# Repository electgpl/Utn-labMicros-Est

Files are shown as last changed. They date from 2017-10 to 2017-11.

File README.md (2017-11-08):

Estación Meteorológica Inalámbrica
=============================

### Introducción
 
Se presentará una estación meteorológica inalámbrica hogareña, la misma consta de dos dispositivos individuales, una estación meteorológica interna que provee de valores dentro del recinto donde se encuentra, y una estación meteorológica externa que provee los valores exteriores, entre ambos dispositivos se realiza la telemetría exterior y se muestra en un display alfanumérico en la estación interior, con la finalidad de observar a primera vista los datos meteorológicos internos y externos.
Esta estación funciona de forma inalámbrica con enlaces de radiofrecuencia y funciona con pilas primarias en el caso exterior y batería recargable en el caso interior.

El proyecto surge de la idea de practicar la programación en lenguaje C, los protocolos de comunicación serie y el transporte de los datos vía enlaces inalambricos, en este proyecto se abordará la estructura necesaria para realizar una trama de datos básica, su payload y verificación.
También se realizará la puesta en marcha del sistema mediante electrónica de bajo costo y bajo consumo para afrontar el problema energético que conlleva la utilización de pilas y baterías de forma competitiva con productos comerciales de la actualidad.

----------
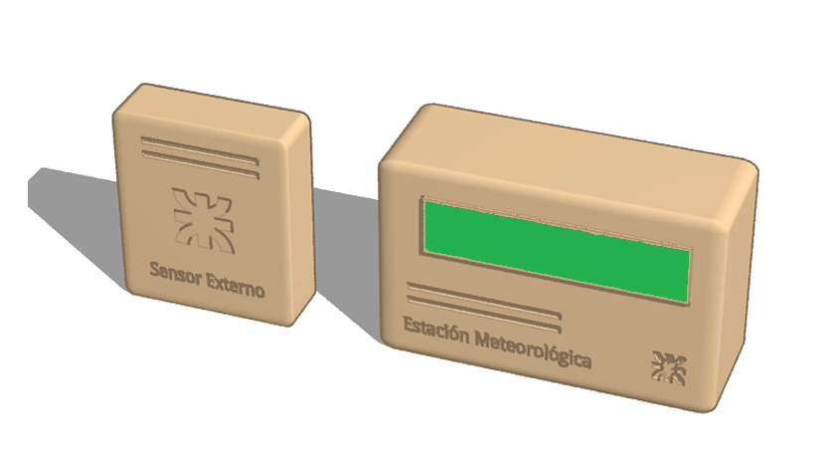
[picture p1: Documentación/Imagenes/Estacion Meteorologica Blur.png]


----------

### Objetivos
 
- Estación meteorológica con medición interna y externa.
- La estación consiste en un sensor externo y uno interno. 
- El sensor externo posee la capacidad de medir Temperatura, Humedad y Luminosidad. 
- El sensor interno mide Temperatura y Humedad. 
- La telemetría se realiza mediante un enlace inalámbrico simplex UHF, el sensor externo funciona mediante celdas primarias alcalinas y posee electrónica de bajo consumo proporcionando una autonomía de 1 año.
- El sensor interno posee un display de LCD de 2 lineas y 16 caracteres que mostrará la Temperatura y Humedad del sensor interno, la Temperatura, Humedad y Luminosidad del sensor externo.
- El sensor interno cuenta con una batería secundaria de iones de litio recargable mediante un conector micro usb.

> **Nota:**
> - El microcontrolador utilizado se basa en core 8051 (para el cual el firmware se encuentra compilado con Keil sobre un microcontrolador de Silabs C8051F832).
> - Se ha realizado también para Microchip sobre diversas plataformas
> - La simulación se realiza para Microchip sobre Proteus.
> - Los diagramas, PCB y Gerber, son realizados con Eagle.

----------

### Diseño conceptual
 
Para realizar nuestra estación, utilizaremos microcontroladores modernos de bajo consumo y bajo costo, que permite trabajar con una buena autonomía utilizando pilas primarias para aumentar al máximo el rendimiento del sistema.
La estación meteorológica utilizara la función especial del microcontrolador para entrar en modo bajo consumo y así extender la batería.
Una vez en bajo consumo se despertara de forma automática mediante el WDT del microcontrolador cada 10 segundos, se tomará una muestra de temperatura, humedad y luminosidad, se enviará mediante el enlace de RF a la estación interna y luego se volverá a dormir entrando en bajo consumo.
El enlace se ha simplificado al máximo para reducir el costo, se utiliza modulación ASK en UHF mediante oscilador a cristal SAW de 433.92MHz y se enviaran los datos mediante UART invertida a 600bps.
En la estación interior, se utilizara la interrupción de dato presente en UART para atender la telemetría exterior, realizar el parse de la trama y dejarla disponible para la utilización.
Se tomará humedad y temperatura interior, y junto con la telemetría exterior se mostrará todo en un dsiplay LCD de 2x16 caracteres alfanuméricos.
La estación interna cuenta con baterías recargables y su controlador de carga para ser conectado directamente con un cable estándar micro usb.

----------
## Implementación
### Especificaciones de Hardware:
#### Dispositivo Interno:
- Sensor de Temperatura y Humedad, DHT11 (comunicación onWire propietaria).
- Receptor modular RWS simplex UHF operando en la banda de 70cm en 433.92MHz, modulación ASK OOK utilizando protocolo RS232, Antena del tipo microstrip IFA 50 Ohms.
- Display LCD 2x16 con controlador HD44780, para mostrar Temp, Hum, (Interna y Externa), Luminosidad (Externa).
- Cargador de Batería tipo Secundaria Li-Ion con micro USB basado en controlador TP4056, Celda 18650, 4800mAh (típico) .
- Microcontrolador de 8bit Silabs C8051F832.
- Circuito impreso hasta 2 Layer con PTH y tecnologia SMD. 
- Aceptación IPC-356, IPC-600, UL-94.

#### Dispositivo Externo:
- Sensor de Temperatura y Humedad, DHT11 (comunicación onWire propietaria).
- Sensor de Luminosidad basado en LDR con acondicionamiento por firmware.
- Transmisor modular TWS simplex UHF operando en la banda de 70cm en 433.92MHz, modulación ASK OOK utilizando protocolo RS232, Antena del tipo microstrip IFA 50 Ohms.
- Batería del tipo primaria alcalina ZnMnO2 tamaño AA, 2500mAh (típico).
- Microcontrolador de 8bit Silabs C8051F832.
- Circuito impreso hasta 2 Layer con PTH y tecnologia SMD. 
- Aceptación IPC-356, IPC-600, UL-94.

### Especificaciones de Firmware:
El firmware debe contar con estándares de programación, encabezado del programa, descripción, autores, versionado, fechas y referencias.
Las funciones deben contar con los valores de ingreso y egreso a la misma como así el tipo de datos y la descripción de la función.
El programa se realizará en lenguaje C.

- Desarrollo de Bibliotecas necesarias (Estandarizado)
- Pruebas Unitarias de cada Biblioteca con el hardware asociado
- Desarrollo de programa principal
- Manejo de errores
- Creación de diagramas de flujo o estado
- Pruebas Integrados del firmware con todas las Bibliotecas y devices

-------
- Biblioteca para sensor DHT11
>- Manejo de Bus OneWire 5 bytes (4 bytes de datos 1 byte de checksum)
>- Formateo de datos de salida Temperatura: entero sin signo de 8bit
>- Formateo de datos de salida Humedad: entero sin signo de 8bit

- Biblioteca de control del LCD
>- Mapeo de los 2 renglones y 16 caracteres.
>- Control de memoria mediante bus de 4bit y control.
>- Entrada mediante string con control xy de caracteres.

- Biblioteca bitbanging para protocolo manchester en los enlaces UHF
>- BitBanging de del protocolo.
>- Realización de Checksum
>- Salida de datos en formato hexadecimal.
>- Entrada de datos en formato hexadecimal.

- Biblioteca del sensor de luminosidad
>- Utilización del conversor analogico digital provisto por el microcontrolador.
>- Configuración de baja velocidad a resolución de 8bit.
>- Salida datos en formato entero.

- Manejo de Baja Energía
>- Apagado de dispositivos periféricos en desuso mediante transistores NMOS.
>- Reloj WDT para función WakeUp del MCU cada 2.3s
>- Si los datos a medir (sensores) no cambian respecto a la medición anterior, no se enviaran datos repetidos mejorando el consumo.

--------

### Especificaciones Técnicas:

Rango de temperatura 0-50°c (precisión ±2°c) 
Rango de humedad 20-90%RH (precisión ±5％) 
Rango de luminosidad 0-100% (precisión ±20％)    
Rango de trabajo hasta 20m Frecuencia de trabajo 433MHz 
Batería de sensor 2xAA Alcalina 
Vida útil de 2 años 
Batería de cuerpo 1x18650
Vida útil Recargable via USB 
Medidas cuerpo 113x67x27.5mm 
Medidas Sensor 91x70x32.5mm 
Gabinete exterior IPX3 
Este equipo no dispone de protección ATEX, por lo que no debe ser usado en atmósferas potencialmente explosivas (polvo, gases inflamables).

--------

### Conclusiones
 
Se ha logrado implementar una estación meteorológica hogareña de bajo consumo y bajo costo que presenta una propuesta comercial respecto a las competidoras de mismas prestaciones.

Se implementó el código necesario para realizar el proyecto sobre core 8051 bajo una plataforma moderna que opera en 16MHz y 16MIPS.
Se realizó todo el tratamiento de la trama, preámbulo, payload, checksum y parseo de datos para realizar el enlace de telemetría entre los dos dispositivos.
Se analizó la velocidad de transferencia de datos sobre UART para lograr la mejor comunicación y alcance sobre módulos de RF de bajo costo.
Se comprobó el diseño de la antena con la ayuda de instrumental adecuado “VNA” para su correcta adaptación.

--------

### Bibliografía
 
- [1] “Manual 8051 Keil”, 
http://www.keil.com/support/man/docs/is51/
- [2] “Manual Eagle”, 
http://hades.mech.northwestern.edu/images/b/b4/Eagle_Manual.pdf
- [3] “Norma ATEX”, 
http://www.insht.es/InshtWeb/Contenidos/Normativa/GuiasTecnicas/Ficheros/ATM%C3%93SFERAS%20EXPLOSIVAS.pdf
- [4] “Norma IPX3”, 
http://hades.mech.northwestern.edu/images/b/b4/Eagle_Manual.pdfhttp://www.f2i2.net/documentos/lsi/rbt/guias/guia_bt_anexo_1_sep03R1.pdf
- [5] “Norma IPC610”, 
http://www.ipc.org/TOC/IPC-A-610E-Spanish.pdf
- [6] “Datasheet DHT11”, 
https://akizukidenshi.com/download/ds/aosong/DHT11.pdf
- [7] “Datasheet Modulos Transmisor y Receptor RF UHF”, https://4.imimg.com/data4/AJ/NM/MY-1833510/rf-transmitter-receiver-pair-433-mhz-ask.pdf
- [8] “Datasheet LDR”, 
http://kennarar.vma.is/thor/v2011/vgr402/ldr.pdf
- [9] “Datasheet C8051F832 Silabs”, https://www.silabs.com/documents/public/data-sheets/C8051F80x-83x.pdf
- [10] “Datasheet TP4056”, https://dlnmh9ip6v2uc.cloudfront.net/datasheets/Prototyping/TP4056.pdf

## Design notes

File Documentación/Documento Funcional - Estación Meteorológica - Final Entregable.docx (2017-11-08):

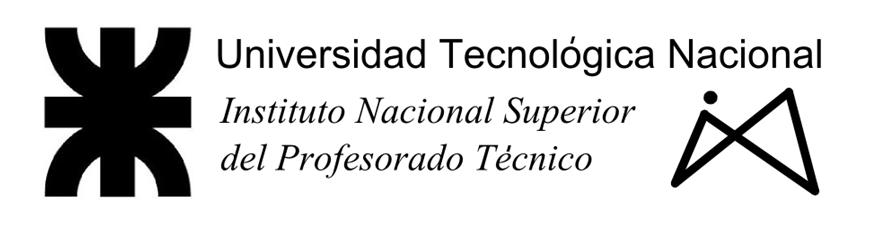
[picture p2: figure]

Robótica

Materia: Laboratorio de Microprocesadores

Curso: 3-631

Año: 2017

Trabajo Práctico Nro. 1

Argumento: Proyecto - Estación Meteorológica Inalámbrica.

Integrantes del Equipo: Caccavallo, Sebastian

Gerbec, Rodrigo

Leuenberger, Leonardo

Responsable del Informe: Caccavallo Sebastian

Profesor: Steiner, Daniel.

Fecha de realización del T.P. | / /
1ra. Fecha de presentación | / /
2da. Fecha de presentación | / /
Calificación
Fecha de Aprobación | / /
FIRMA: ………………………. | ACLARACIÓN: ……………….………………...

Introducción

Se presentará una estación meteorológica inalámbrica hogareña, la misma consta de dos dispositivos individuales, una estación meteorológica interna que provee de valores dentro del recinto donde se encuentra, y una estación meteorológica externa que provee los valores exteriores, entre ambos dispositivos se realiza la telemetría exterior y se muestra en un display alfanumérico en la estación interior, con la finalidad de observar a primera vista los datos meteorológicos internos y externos.

Esta estación funciona de forma inalámbrica con enlaces de radiofrecuencia y funciona con pilas primarias en el caso exterior y batería recargable en el caso interior.

El proyecto surge de la idea de practicar la programación en lenguaje C, los protocolos de comunicación serie y el transporte de los datos vía enlaces inalambricos, en este proyecto se abordará la estructura necesaria para realizar una trama de datos básica, su payload y verificación.

También se realizará la puesta en marcha del sistema mediante electrónica de bajo costo y bajo consumo para afrontar el problema energético que conlleva la utilización de pilas y baterías de forma competitiva con productos comerciales de la actualidad.

Objetivos

- Estación meteorológica con medición interna y externa.
- La estación consiste en un sensor externo y uno interno.
- El sensor externo posee la capacidad de medir Temperatura, Humedad y Luminosidad.
- El sensor interno mide Temperatura y Humedad.
- La telemetría se realiza mediante un enlace inalámbrico simplex UHF, el sensor externo funciona mediante celdas primarias alcalinas y posee electrónica de bajo consumo proporcionando una autonomía de 1 año.
- El sensor interno posee un display de LCD de 2 lineas y 16 caracteres que mostrará la Temperatura y Humedad del sensor interno, la Temperatura, Humedad y Luminosidad del sensor externo.
- El sensor interno cuenta con una batería secundaria de iones de litio recargable mediante un conector micro usb.
- Look&Feel del LCD (VER FIGURA EN EL APARTADO)

Diseño conceptual

Para realizar nuestra estación, utilizaremos microcontroladores modernos de bajo consumo y bajo costo, que permite trabajar con una buena autonomía utilizando pilas primarias para aumentar al máximo el rendimiento del sistema.

La estación meteorológica utilizara la función especial del microcontrolador para entrar en modo bajo consumo y así extender la batería.

Una vez en bajo consumo se despertara de forma automática mediante el WDT del microcontrolador cada 10 segundos, se tomará una muestra de temperatura, humedad y luminosidad, se enviará mediante el enlace de RF a la estación interna y luego se volverá a dormir entrando en bajo consumo.

El enlace se ha simplificado al máximo para reducir el costo, se utiliza modulación ASK en UHF mediante oscilador a cristal SAW de 433.92MHz y se enviaran los datos mediante UART invertida a 600bps.

En la estación interior, se utilizara la interrupción de dato presente en UART para atender la telemetría exterior, realizar el parse de la trama y dejarla disponible para la utilización.

Se tomará humedad y temperatura interior, y junto con la telemetría exterior se mostrará todo en un dsiplay LCD de 2x16 caracteres alfanuméricos.

La estación interna cuenta con baterías recargables y su controlador de carga para ser conectado directamente con un cable estándar micro usb.

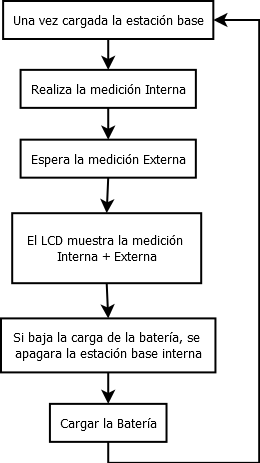
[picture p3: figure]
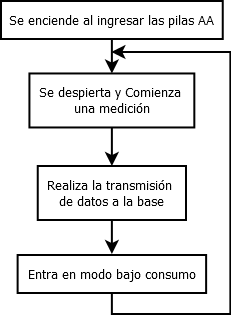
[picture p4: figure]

Diseño de alto nivel

Diagrama de bloques de Hardware Interior:

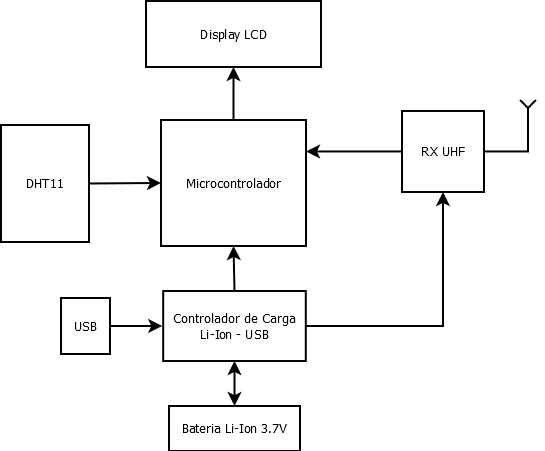
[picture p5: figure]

Diagrama de bloques de Hardware Exterior:

Diagrama de bloques de Firmware Interior:

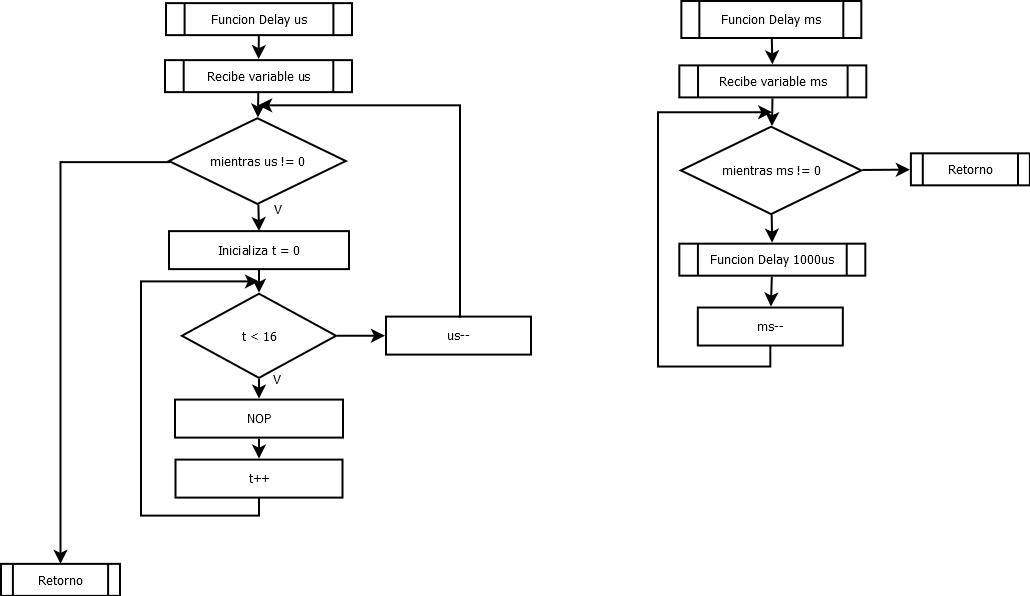
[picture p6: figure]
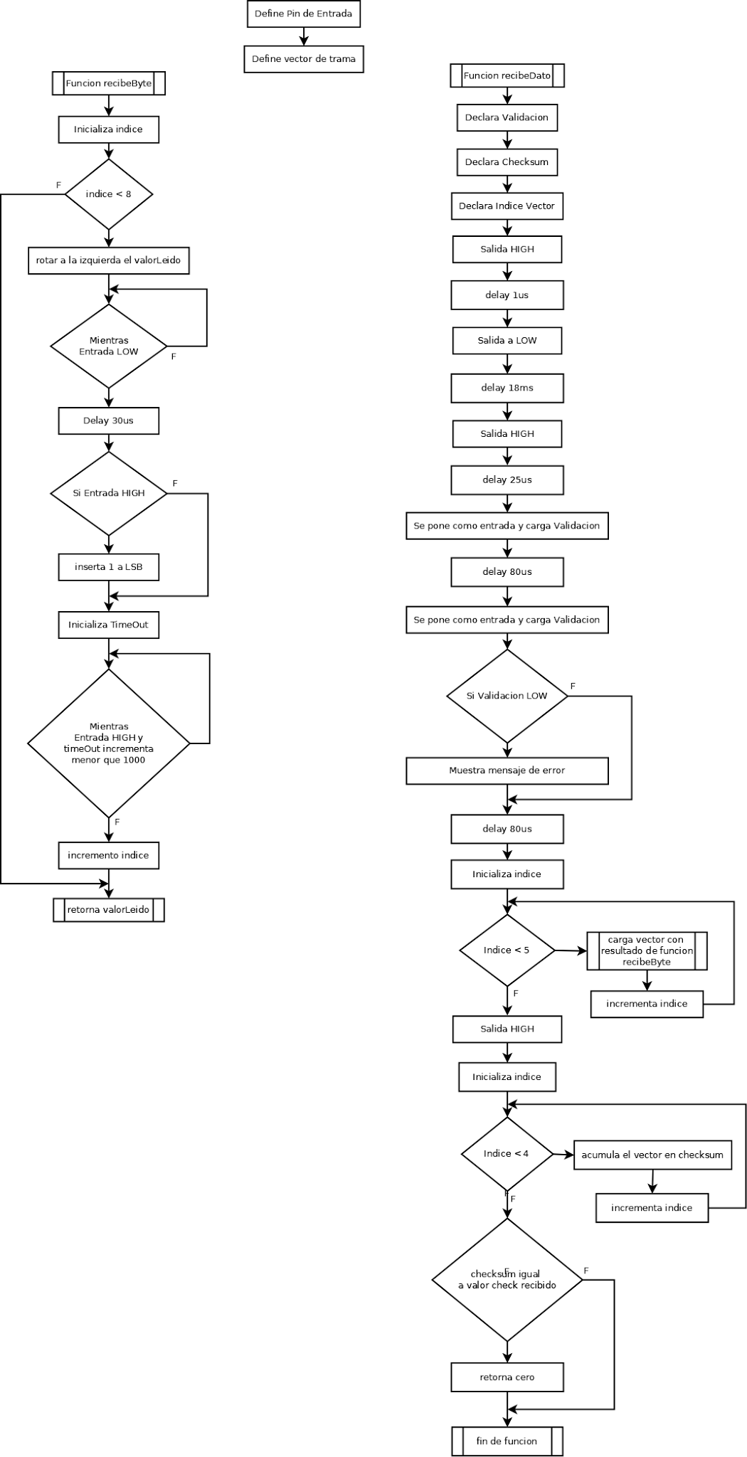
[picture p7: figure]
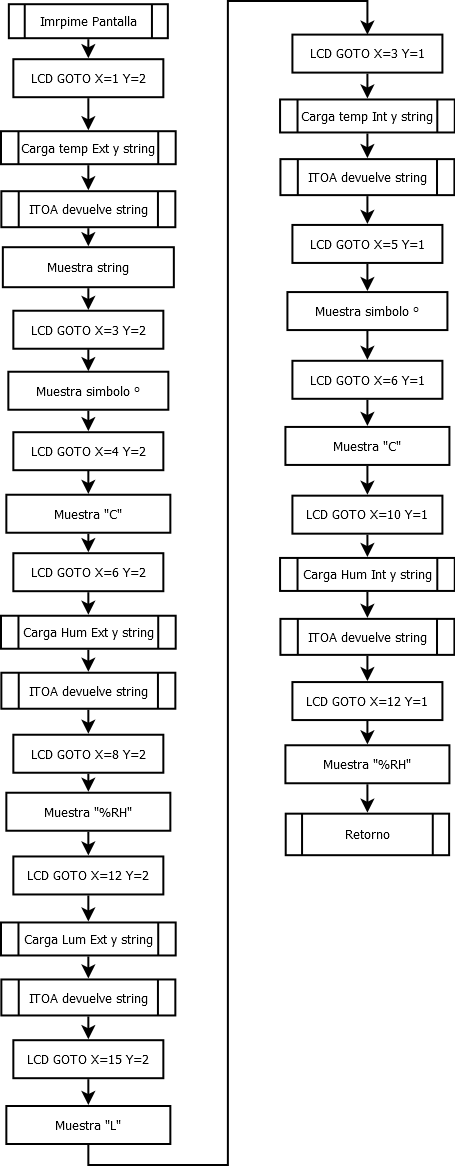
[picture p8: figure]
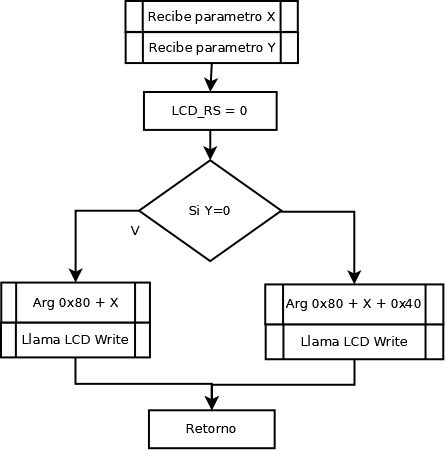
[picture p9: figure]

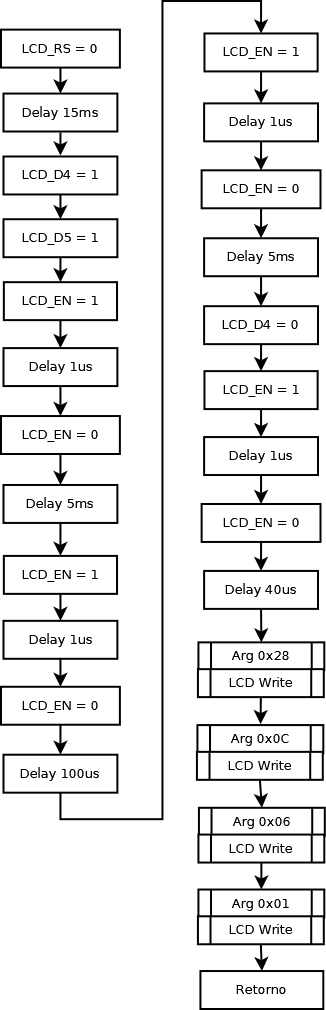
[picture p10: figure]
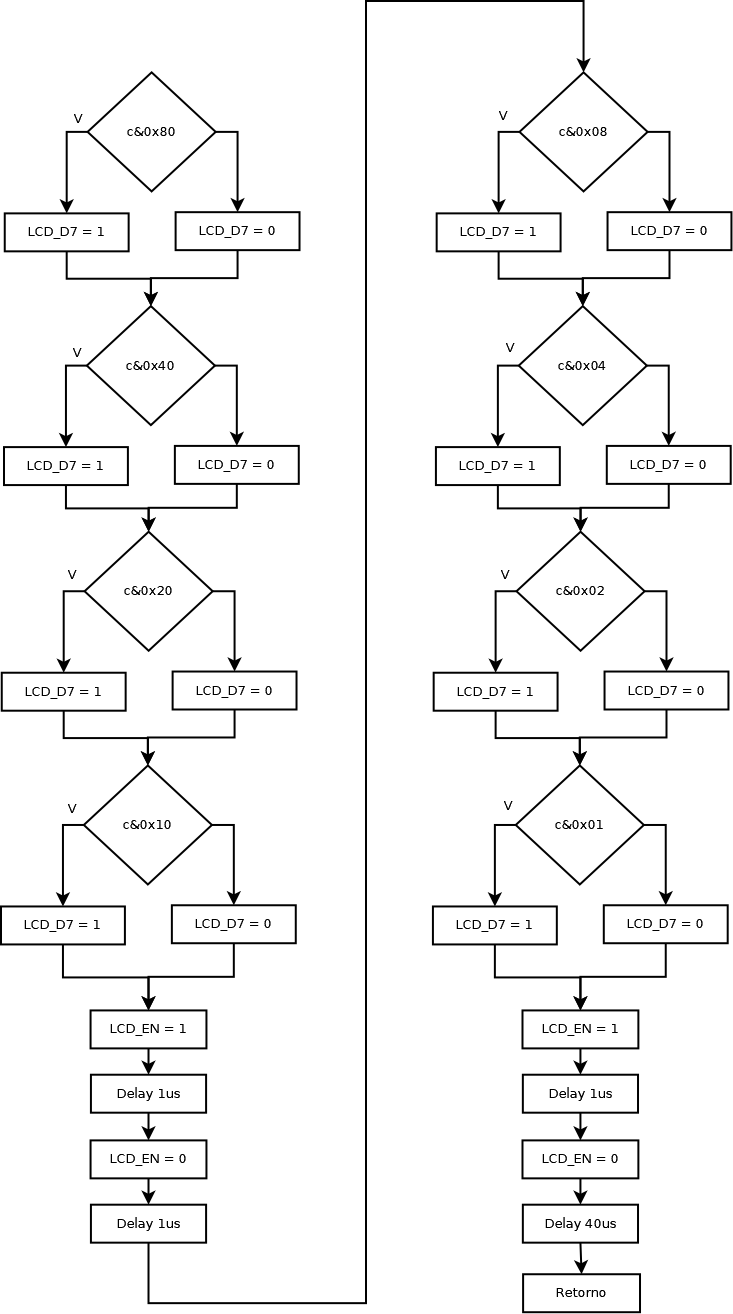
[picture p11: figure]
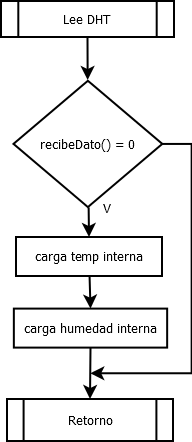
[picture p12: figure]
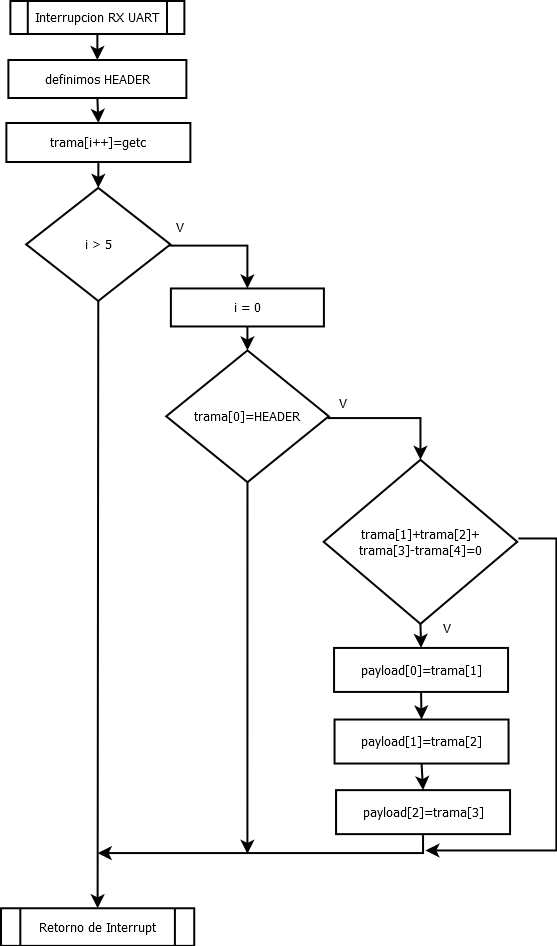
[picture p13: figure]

Diagrama de bloques de Firmware Exterior:

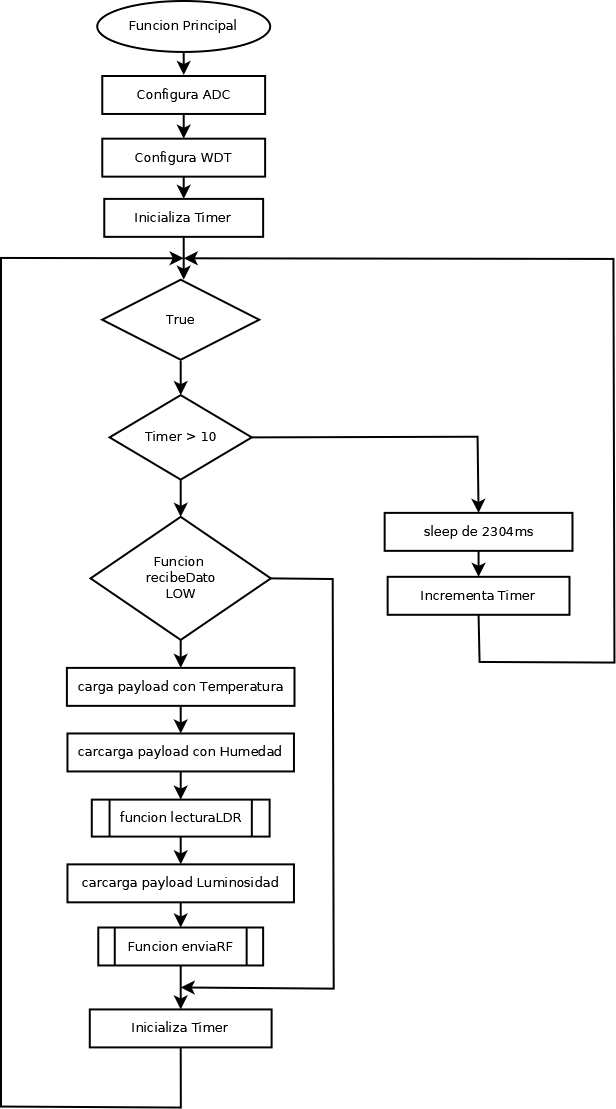
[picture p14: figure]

Implementación

### Especificaciones de Hardware:

### Dispositivo Interno:

- Sensor de Temperatura y Humedad, DHT11 (comunicación onWire propietaria).
- Receptor modular RWS simplex UHF operando en la banda de 70cm en 433.92MHz, modulación ASK OOK utilizando protocolo RS232, Antena del tipo microstrip IFA 50 Ohms.
- Display LCD 2x16 con controlador HD44780, para mostrar Temp, Hum, (Interna y Externa), Luminosidad (Externa).
- Cargador de Batería tipo Secundaria Li-Ion con micro USB basado en controlador TP4056, Celda 18650, 4800mAh (típico) .
- Microcontrolador de 8bit Silabs C8051F832.
- Circuito impreso hasta 2 Layer con PTH y tecnologia SMD.
- Aceptación IPC-356, IPC-600, UL-94.

### Dispositivo Externo:

- Sensor de Temperatura y Humedad, DHT11 (comunicación onWire propietaria).
- Sensor de Luminosidad basado en LDR con acondicionamiento por firmware.
- Transmisor modular TWS simplex UHF operando en la banda de 70cm en 433.92MHz, modulación ASK OOK utilizando protocolo RS232, Antena del tipo microstrip IFA 50 Ohms.
- Batería del tipo primaria alcalina ZnMnO2 tamaño AA, 2500mAh (típico).
- Microcontrolador de 8bit Silabs C8051F832.
- Circuito impreso hasta 2 Layer con PTH y tecnologia SMD.
- Aceptación IPC-356, IPC-600, UL-94.

### Especificaciones de Firmware:

El firmware debe contar con estándares de programación, encabezado del programa, descripción, autores, versionado, fechas y referencias.

Las funciones deben contar con los valores de ingreso y egreso a la misma como así el tipo de datos y la descripción de la función.

El programa se realizará en lenguaje C.

- Desarrollo de Bibliotecas necesarias (Estandarizado)
- Pruebas Unitarias de cada Biblioteca con el hardware asociado
- Desarrollo de programa principal
- Manejo de errores
- Creación de diagramas de flujo o estado
- Pruebas Integrados del firmware con todas las Bibliotecas y devices
- Biblioteca para sensor DHT11
  - Manejo de Bus OneWire 5 bytes (4 bytes de datos 1 byte de checksum)
  - Formateo de datos de salida Temperatura: entero sin signo de 8bit
  - Formateo de datos de salida Humedad: entero sin signo de 8bit
- Biblioteca de control del LCD
  - Mapeo de los 2 renglones y 16 caracteres.
  - Control de memoria mediante bus de 4bit y control.
  - Entrada mediante string con control xy de caracteres.
- Biblioteca bitbanging para protocolo manchester en los enlaces UHF
  - BitBanging de del protocolo.
  - Realización de Checksum
  - Salida de datos en formato hexadecimal.
  - Entrada de datos en formato hexadecimal.
- Biblioteca del sensor de luminosidad
  - Utilización del conversor analogico digital provisto por el microcontrolador.
  - Configuración de baja velocidad a resolución de 8bit.
  - Salida datos en formato entero.
- Manejo de Baja Energía
  - Apagado de dispositivos periféricos en desuso mediante transistores NMOS.
  - Reloj WDT para función WakeUp del MCU cada 2.3s
  - Si los datos a medir (sensores) no cambian respecto a la medición anterior, no se enviaran datos repetidos mejorando el consumo.

Especificaciones Técnicas:

Rango de temperatura 0-50°c (precisión ±2°c)
Rango de humedad 20-90%RH (precisión ±5％)

Rango de luminosidad 0-100% (precisión ±20％)

Rango de trabajo hasta 20m
Frecuencia de trabajo 433MHz

Batería de sensor 2xAA Alcalina - Vida útil de 2 años

Batería de cuerpo 1x18650 - Vida útil Recargable via USB

Medidas cuerpo 113x67x27.5mm
Medidas Sensor 91x70x32.5mm

Gabinete exterior IPX3

Este equipo no dispone de protección ATEX, por lo que no debe ser usado en atmósferas potencialmente explosivas (polvo, gases inflamables).

Look & Feel de pantalla:

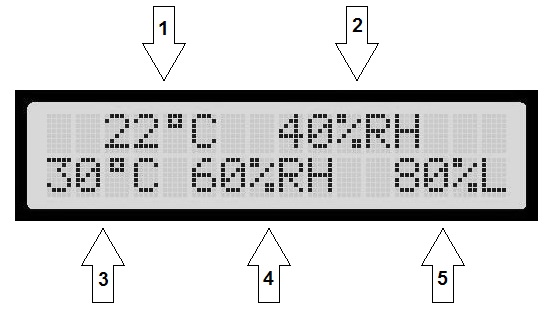
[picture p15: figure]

| 1) Temperatura Interior 2) Humedad Interior 3) Temperatura Exterior 4) Humedad Exterior 5) Cantidad de Luz Exterior

Trama implementada para el enlace:

Diagrama Electronico Interior:

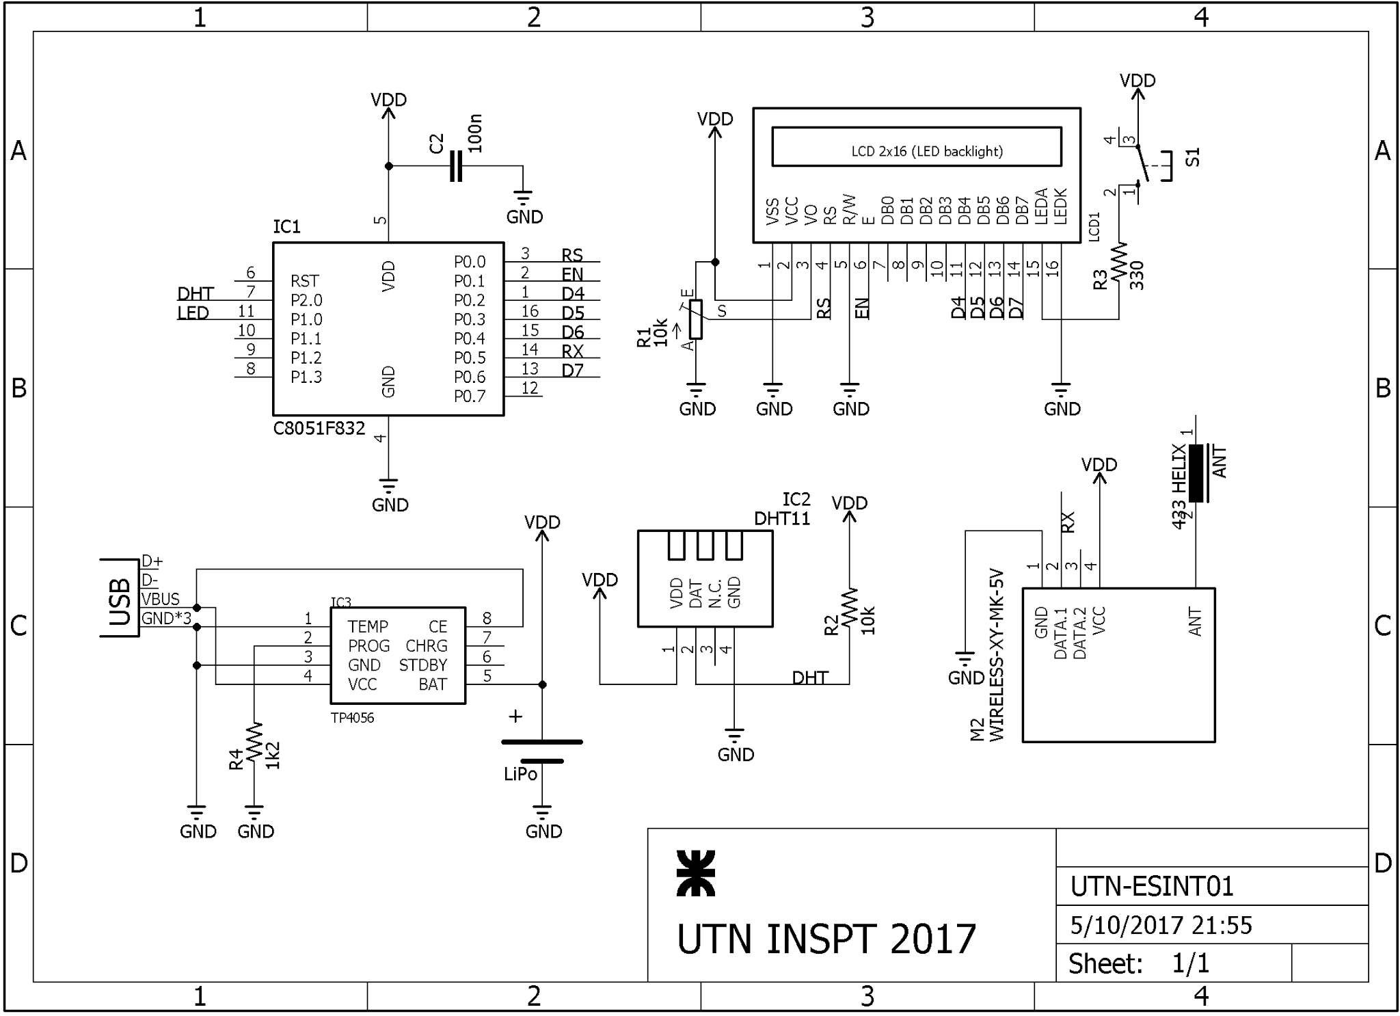
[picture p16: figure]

Diagrama Electronico Exterior:

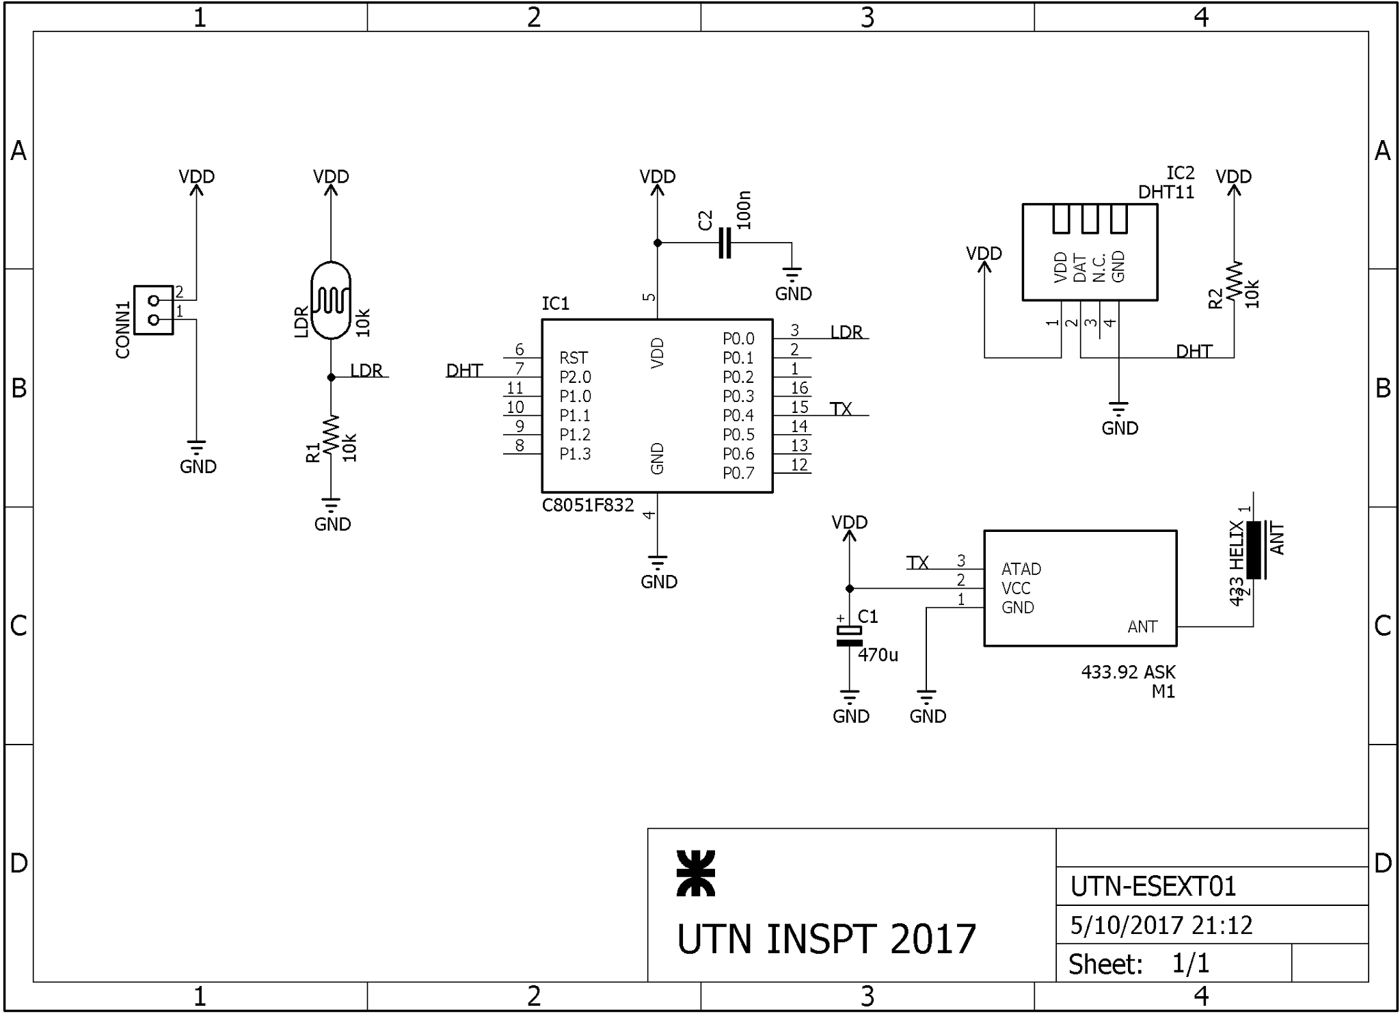
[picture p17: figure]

Circuito Impreso Interior:

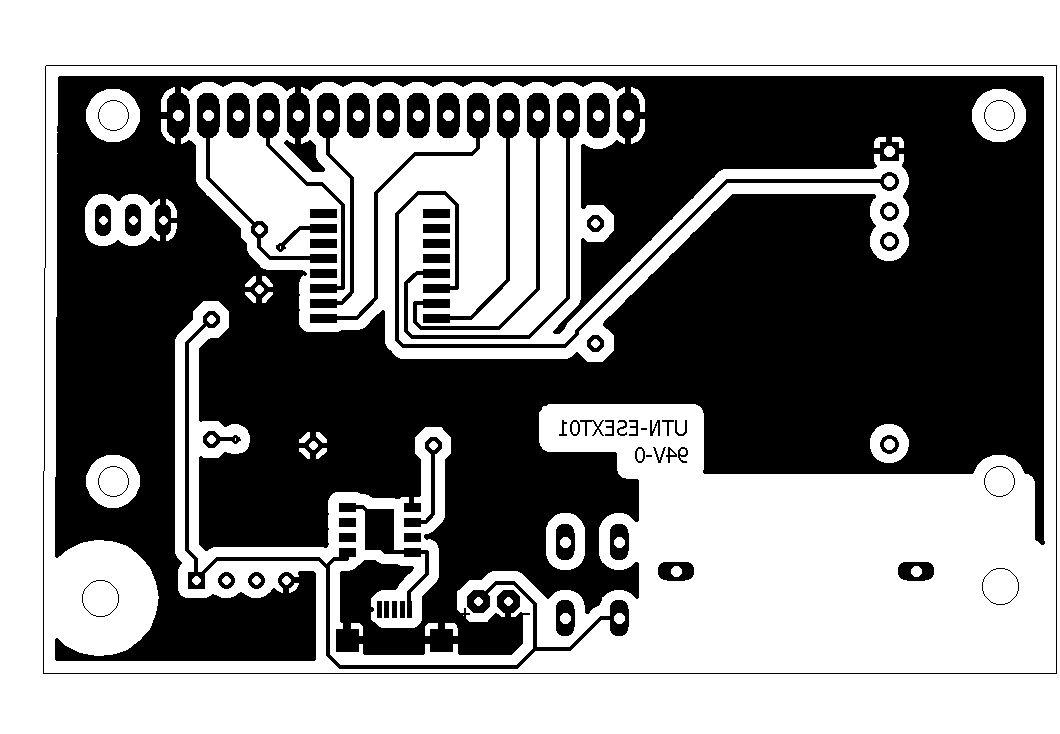
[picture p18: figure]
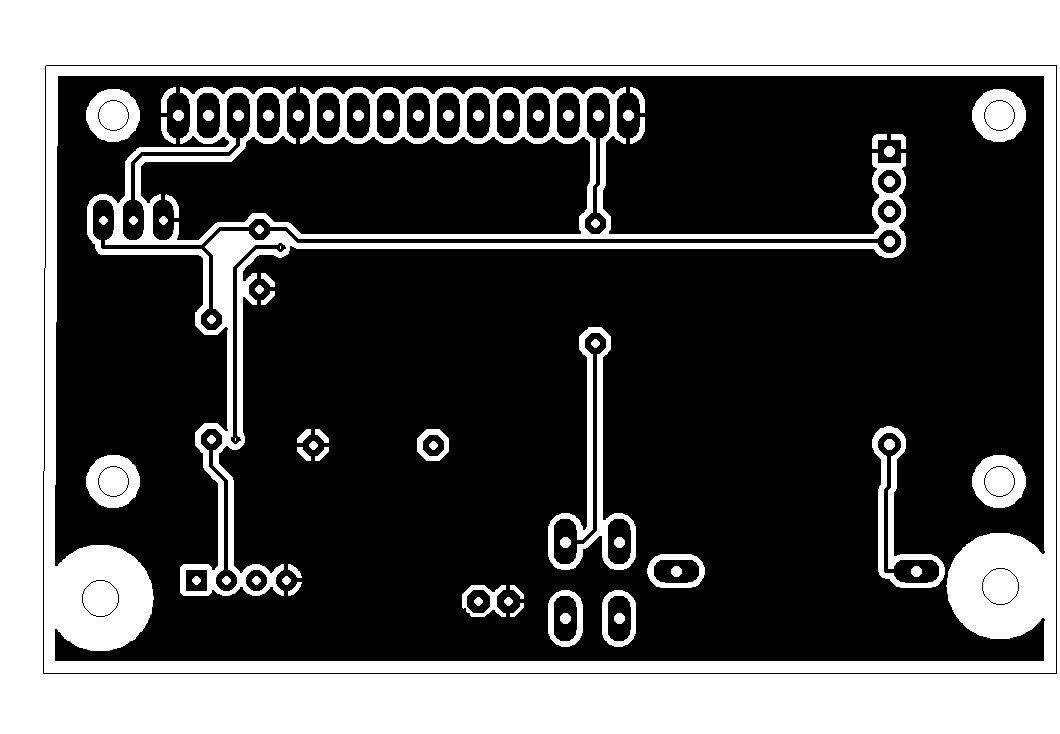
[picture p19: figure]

Circuito Impreso Exterior:

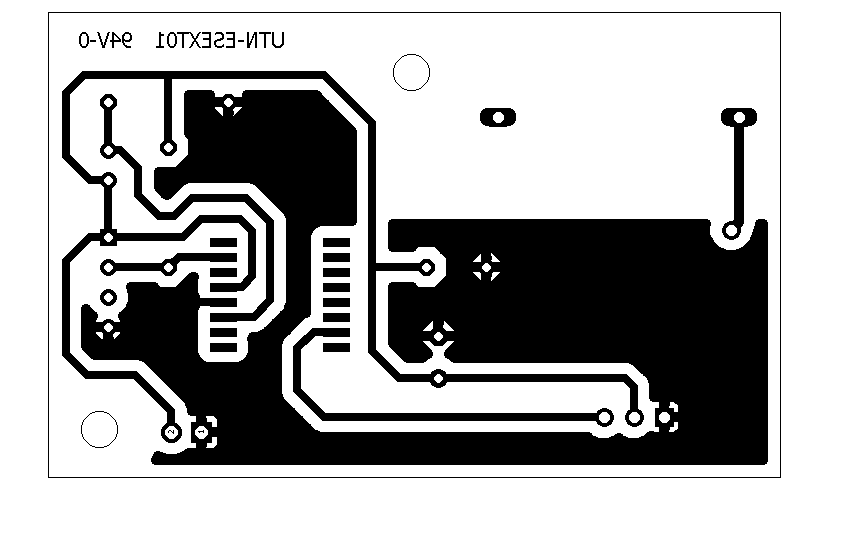
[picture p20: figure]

Análisis de antena tipo ANT-433-HETH:

Código del proyecto

Firmware Interior (Silabs C8051F832):

1. //*********************************************************************************************************
2. // Programa para la estación meteorológica Interna inalámbrica
3. // El programa recibe Temperatura, Humedad y Luminosidad por interrupción
4. // El sistema mide Temperatura y Humedad interior
5. // El enlace se realiza mediante una comunicación ASK OOK UHF sobre UART Invertido a 600bps
6. // Se muestra medición interna y externa en un LCD de 2x16
7. // Microcontrolador Silabs C8051F832
8. //*********************************************************************************************************
9. #include <REG51F800.H>
10. #include <reg52.h>
11. #include <intrins.h>
12. #include <stdio.h>
13. //*********************************************************************************************************
14. // Variables
15. //*********************************************************************************************************
16. #define HEADER 200 //Definición de valor Header para el payload
17. sbit DATA = P1^0; //Pin del bus de un hilo para el DHT11
18. static int datoInt[2]; //Variable donde se alojan los datos internos
19. static int payload[5]; //Variable donde se aloja el payload
20. static int datoExt[3]; //Variable donde se alojan los datos externos
21. //*********************************************************************************************************
22. // Configuración de pines del LCD
23. //*********************************************************************************************************
24. extern bit RS; //Definición de pines
25. extern bit EN; //Definición de pines
26. extern bit D4; //Definición de pines
27. extern bit D5; //Definición de pines
28. extern bit D6; //Definición de pines
29. extern bit D7; //Definición de pines
30. sbit RS = P2^0; //Definición de pines
31. sbit EN = P2^1; //Definición de pines
32. sbit D4 = P2^4; //Definición de pines
33. sbit D5 = P2^5; //Definición de pines
34. sbit D6 = P2^6; //Definición de pines
35. sbit D7 = P2^7; //Definición de pines
36. //*********************************************************************************************************
37. // delay_us Bloqueante Micro Segundos
38. //*********************************************************************************************************
39. void delay_us(unsigned int us_count){ //Función para delay_ms de micro-segundos
40. int t=0;
41. while(us_count!=0){ //Mientras que el contador es distinto de cero
42. for(t=0;t<16;t++){ //16MIPS dividido en 16 para 1us
43. _nop_(); //Ejecuta función NOP de ensamblador
44. }
45. us_count--; //Decremento del valor de delay_ms
46. }
47. }
48. //*********************************************************************************************************
49. // delay_ms Bloqueante Mili Segundos
50. //*********************************************************************************************************
51. void delay_ms(unsigned int us_count){ //Función para delay_ms de micro-segundos
52. while(us_count!=0){ //Mientras que el contador es distinto de cero
53. delay_us(1000); //Ejecuta funcion delay_ms micro segundos
54. us_count--; //Decremento del valor de delay_ms
55. }
56. }
57. //*********************************************************************************************************
58. // Funcion que escribe en puerto
59. //*********************************************************************************************************
60. void lcdPort(char a){ //Funcion para escribir el puerto en 4bit
61. if(a&1) D4=1; //Evalúa si a AND 0001, D4 a HIGH
62. else D4=0; //Caso contrario D4 a LOW
63. if(a&2) D5=1; //Evalúa si a AND 0010, D5 a HIGH
64. else D5=0; //Caso contrario D5 a LOW
65. if(a&4) D6=1; //Evalúa si a AND 0100, D6 a HIGH
66. else D6=0; //Caso contrario D6 a LOW
67. if(a&8) D7=1; //Evalúa si a AND 1000, D7 a HIGH
68. else D7=0; //Caso contrario D7 a LOW
69. }
70. //*********************************************************************************************************
71. // Funcion que envia comando
72. //*********************************************************************************************************
73. void lcdCmd(char a){ //Función para realizar comandos en LCD
74. RS=0; //Control RS a LOW
75. lcdPort(a); //Llamado a lcdPort
76. EN=1; //Control EN a HIGH
77. delay_ms(5); //Espera de 5ms
78. EN=0; //Control EN a LOW
79. }
80. //*********************************************************************************************************
81. // Borrado de LCD
82. //*********************************************************************************************************
83. lcdClear(){ //Función para borrar el LCD
84. lcdCmd(0); //Se envia comando LOW
85. lcdCmd(1); //Se envía comando HIGH
86. }
87. //*********************************************************************************************************
88. // Función para ir a la posición específica
89. //*********************************************************************************************************
90. void lcdGotoxy(char b, char a){ //Función para posicionar el cursor
91. char temp,z,y; //Declaración de variables
92. if(a==1){ //Si se encuentra en renglón 1
93. temp=0x80+b; //Se incrementa la columna
94. z=temp>>4; //Se realiza el desplazamiento
95. y=temp&0x0F; //Se aplica la máscara de bits
96. lcdCmd(z); //Envía comandos
97. lcdCmd(y); //Envía comandos
98. }else{ //Si no está en renglón 1
99. if(a==2){ //Si se encuentra en renglón 2
100. temp=0xC0+b; //Se incrementa la columna
101. z=temp>>4; //Se realiza el desplazamiento
102. y=temp&0x0F; //Se realiza la máscara
103. lcdCmd(z); //Envía comandos
104. lcdCmd(y); //Envía comandos
105. }
106. }
107. }
108. //*********************************************************************************************************
109. // Inicializa LCD
110. //*********************************************************************************************************
111. void lcdInit(){ //Función para inicializar el LCD
112. lcdPort(0x00); //Se envía 0000 0000
113. delay_ms(200); //Delay de 200ms
114. lcdCmd(0x03); //Se envía 0000 0011
115. delay_ms(50); //Delay de 50ms
116. lcdCmd(0x03); //Se envía 0000 0011
117. delay_ms(110); //Delay de 110ms
118. lcdCmd(0x03); //Se envía 0000 0011
119. lcdCmd(0x02); //Se envía 0000 0010
120. lcdCmd(0x02); //Se envía 0000 0010
121. lcdCmd(0x08); //Se envía 0000 1000
122. lcdCmd(0x00); //Se envía 0000 0000
123. lcdCmd(0x0C); //Se envía 0000 1100
124. lcdCmd(0x00); //Se envía 0000 0000
125. lcdCmd(0x06); //Se envía 0000 0110
126. }
127. //*********************************************************************************************************
128. // Función para escribir caracter
129. //*********************************************************************************************************
130. void lcdWriteChar(char a){ //Funcion para escribir un caracter
131. char temp,y; //Declaración de variables
132. temp=a&0x0F; //Se realiza la máscara de bits 0000 1111
133. y=a&0xF0; //Se realiza la máscara de bits 0000 1111
134. RS=1; //Control RS a HIGH
135. lcdPort(y>>4); //Se desplaza 4 lugares a la derecha
136. EN=1; //Control EN a HIGH
137. delay_ms(5); //Delay de 5ms
138. EN=0; //Control EN a LOW
139. lcdPort(temp); //Se envía el valor
140. EN=1; //Control EN a HIGH
141. delay_ms(5); //Delay de 5ms
142. EN=0; //Control EN a LOW
143. }
144. //*********************************************************************************************************
145. // Función para escribir string
146. //*********************************************************************************************************
147. void lcdWriteString(char *a){ //Funcion para escribir string
148. int i; //Declaración de variables
149. for(i=0;a[i]!='\0';i++) //Iteración de caracteres hasta el NULL
150. lcdWriteChar(a[i]); //Se carga cada caracter para formar string
151. }
152. //*********************************************************************************************************
153. // Función ITOA para convertir entero en ascii
154. //*********************************************************************************************************
155. char *itoa(long int num, char *s){ //Función ITOA (Entero to ASCII)
156. unsigned long int temp=1; //Declaración de valor temporal
157. unsigned int i, cnt=0; //Declaración de índices y contadores
158. char c; //Declaración de variable de carácter de salida
159. while(temp>0){ //Rutina de Conversión (Queda invertida)
160. temp=(num/10); //Conversión de carácter a carácter
161. s[cnt]=(num%10)+'0'; //utilizando divisiones y resto
162. if(s[cnt]>0x39) //sumando el offset de la tabla ASCII
163. s[cnt]+=0x7;
164. cnt++;
165. num=temp;
166. }
167. for(i=0;i<(int)(cnt/2);i++){ //Rutina para invertir el numero convertido
168. c=s[i]; //Intercambio de variables
169. s[i]=s[cnt-i-1];
170. s[cnt-i-1]=c;
171. }
172. s[cnt]='\0'; //Carácter nulo, fin de la conversión ITOA
173. return s; //Retorno del valor ASCII
174. }
175. //*********************************************************************************************************
176. // Funcion para inicializar el puerto serie 9600 @ 11.059MHz
177. //*********************************************************************************************************
178. void serialInit(void){ //Función para configurar UART
179. TMOD=0x20; //Timer 1 en modo 2 - Auto recarga para generar Baudrate
180. SCON=0x50; //Serial modo 1, 8N1
181. TH1=0xFD; //Carga el baudrate en el timer a 9600bps
182. TR1=1; //Dispara el timer
183. }
184. //*********************************************************************************************************
185. // Función Interrupción UART que realiza el parse de datos, validación de Header y Checksum
186. // Si validación y Checksum son validos, carga el vector DATO para ser utilizado
187. //*********************************************************************************************************
188. char i=0; //Variable para el contador de bytes de entrada
189. void serial_ISR(void) interrupt 4{ //Función de servicio de interrupción
190. if(RI==1){ //Si hay dato pendiente en UART
191. payload[i++]=SBUF; //Guarda byte de entrada en payload. incrementa índice
192. RI=0; //Pone a cero el flag
193. }
194. if(i>5){ //Si índice mayor a 5 se asume que se completa el payload
195. if(payload[0]==HEADER){ //Validación Header sea 200 (seteado en el transmisor)
196. if(payload[1]+payload[2]+payload[3]-payload[4]==0){//Validación, si datos leídos son igual a checksum
197. datoExt[0]=payload[1]; //Cargamos los datos en el vector
198. datoExt[1]=payload[2]; //Cargamos los datos en el vector
199. datoExt[2]=payload[3]; //Cargamos los datos en el vector
200. }
201. }
202. i=0; //Una vez completado 5 bytes, se reinicia el contador
203. }
204. RI=0; //Pone a cero el flag
205. }
206. //*********************************************************************************************************
207. // Trama DHT11 - Segun Datasheet
208. // ____ ____ ____ ___
209. // |___________| |____| |.....................................|
210. // | 18ms | |80us|80us| 5x8 bit |
211. // | PIC | | DHT11 respuesta | Fin de
212. // | request | | 2x80us, intRH, decRH, intT, decT, checksum | Trama
213. // ____ ________
214. // |________| |... 0 bit
215. // <-50us-> <-27us->
216. // ____ _________________________
217. // |________| |... 1 bit
218. // <-50us-> <---------70us---------->
219. //*********************************************************************************************************
220. unsigned int trama[5]; //Vector donde se alojan los datos
221. //*********************************************************************************************************
222. // Función de recepción de Byte
223. // Lee el valor leído en la trama y lo separa realizando shift
224. // Retorna el valor en forma de byte, es utilizado en la función recibeDato()
225. //*********************************************************************************************************
226. unsigned int recibeByte(){ //Función que recibe un Byte
227. unsigned int valorLeido = 0; //Valor de retorno de la función
228. int i=0; //Inicialización del índice
229. for(i=0; i<8; i++){ //Iteración para recepción de bits
230. valorLeido <<= 1; //Registro de desplazamiento de bits
231. while(DATA==0); //Espera a DATA = 0
232. delay_us(30); //Demora de 30us (Del Datasheet)
233. if(DATA==1){ //Pregunta si DATA = 1
234. valorLeido |= 1; //Realiza toggle del valor leído
235. }
236. while(DATA==1); //Espera a DATA = 1
237. }
238. return valorLeido; //Retorna el valor leído
239. }
240. //*********************************************************************************************************
241. // Función de recepción de dato para el DHT11
242. // Recibe los valores de temperatura y humedad (parte entera y decimales por separado)
243. // Recibe el checksum enviado por el DHT11 y lo compara con el leído en el programa
244. //*********************************************************************************************************
245. unsigned int recibeDato(){ //Funcion que recibe el Dato
246. int validacion = 0; //Variable de Validación
247. int checksum = 0; //Variable de detección de cambios de secuencia
248. int j=0; //Variable para el lazo for
249. DATA = 1; //Set DATA = 1
250. DATA = 0; //Set DATA = 0
251. delay_ms(18); //Demora de 18ms (Del Datasheet)
252. DATA = 1; //Set DATA = 1
253. delay_us(25); //Demora de 25ms (Del Datasheet)
254. validacion = DATA; //Mueve valor de DATA a Validacion
255. delay_us(80); //Espera 80us (Del Datasheet)
256. validacion = DATA; //Mueve valor de DATA a Validacion
257. if(!validacion){ //Si Validacion = 0, Error de secuencia
258. printf( "Error en Checksum \r"); //Muestra leyenda de error
259. }
260. delay_us(80); //Espera 80us (Del Datasheet)
261. for(j=0; j<5; j++){ //Lazo de carga de bytes de datos
262. trama[j] = recibeByte(); //Carga del vector de datos
263. }
264. DATA = 1; //Set DATA = 1
265. for(j=0; j<4; j++){ //Lazo de carga de bytes de verificación
266. checksum += trama[j]; //Carga de bytes de verificación
267. }
268. if(checksum == trama[4]){ //Si la secuencia de verificación es correcta
269. return 0; //Se retorna 0 y se realiza la lectura
270. }
271. }
272. //*********************************************************************************************************
273. // Lee DHT11
274. //*********************************************************************************************************
275. void leeDHT11(void){ //Funcion que lee el DHT11
276. if(recibeDato()==0){ //Consulta si hay dato en la entrada del DHT11
277. datoInt[0]=trama[2]; //Carga el valor de temperatura DHT en byte 1 del payload
278. datoInt[1]=trama[0]; //Carga el valor de humedad DHT en byte 2 del payload
279. }
280. }
281. //*********************************************************************************************************
282. // Saludo de Pantalla
283. //*********************************************************************************************************
284. void saludoPantalla(void){ //Función que realiza un saludo inicial
285. lcdGotoxy(1,1); //Posiciona el cursor en la pantalla
286. lcdWriteString(" Est.Inalambrica"); //Imprime mensaje renglon 1
287. lcdGotoxy(1,2); //Posiciona el cursor en la pantalla
288. lcdWriteString(" v1.1 UTN INSPT"); //Imprime mensaje renglón 2
289. delay_ms(2000); //delay_ms de saludo
290. lcdInit(); //Inicializa LCD
291. lcdClear(); //Borra LCD
292. }
293. //*********************************************************************************************************
294. // Impresion de Pantalla
295. //*********************************************************************************************************
296. void impPantalla(void){ //Funcion que imprime pantalla
297. char string[4]; //Declaración de vector para mostrar en LCD
298. lcdGotoxy(1,2); //Posiciona el cursor en la pantalla
299. itoa(datoExt[0],string); //Funcion que convierte entero en ascii
300. lcdWriteString(string); //Muestra en el LCD
301. lcdGotoxy(3,2); //Posiciona el cursor en la pantalla
302. lcdWriteString(0xDF); //Imprime unidad de medida
303. lcdGotoxy(4,2); //Posiciona el cursor en la pantalla
304. lcdWriteString("C"); //Imprime unidad de medida
305. lcdGotoxy(6,2); //Posiciona el cursor en la pantalla
306. itoa(datoExt[1],string); //Funcion que convierte entero en ascii
307. lcdWriteString(string); //Muestra en el LCD
308. lcdGotoxy(8,2); //Posiciona el cursor en la pantalla
309. lcdWriteString("%RH"); //Imprime unidad de medida
310. lcdGotoxy(12,2); //Posiciona el cursor en la pantalla
311. itoa(datoExt[2],string); //Funcion que convierte entero en ascii
312. lcdWriteString(string); //Muestra en el LCD
313. lcdGotoxy(15,2); //Posiciona el cursor en la pantalla
314. lcdWriteString("L"); //Imprime unidad de medida
315. lcdGotoxy(3,1); //Posiciona el cursor en la pantalla
316. itoa(datoInt[0],string); //Funcion que convierte entero en ascii
317. lcdWriteString(string); //Muestra en el LCD
318. lcdGotoxy(5,1); //Posiciona el cursor en la pantalla
319. lcdWriteString(0xDF); //Imprime unidad de medida
320. lcdGotoxy(6,1); //Posiciona el cursor en la pantalla
321. lcdWriteString("C"); //Imprime unidad de medida
322. lcdGotoxy(10,1); //Posiciona el cursor en la pantalla
323. itoa(datoInt[1],string); //Funcion que convierte entero en ascii
324. lcdWriteString(string); //Muestra en el LCD
325. lcdGotoxy(12,1); //Posiciona el cursor en la pantalla
326. lcdWriteString("%RH"); //Imprime unidad de medida
327. }
328. //*********************************************************************************************************
329. // Programa principal, Realiza la lectura de DHT11, lectura de batería y recibe los datos por UART
330. // Lee la temperatura y humedad interna, realiza un pronóstico aproximado
331. //*********************************************************************************************************
332. void main(){ //Funcion principal
333. saludoPantalla(); //Función de saludo de pantalla
334. P1=0x00; //Usado para aplicación
335. P3=0x03; //Usado para el serie
336. serialInit(); //Inicializa puerto serie
337. EA=1; //Habilitacion de interrupcion Global
338. ES=1; //Habilitacion de interrupcion Serie
339. while(1){ //Loop principal infinito
340. leeDHT11(); //Función que lee DHT11
341. delay_ms(2000); //delay_ms de Actualización
342. impPantalla(); //Imprime pantalla LCD
343. delay_ms(2000); //delay_ms de Actualización
344. }
345. }

Firmware Exterior (Silabs C8051F832):

1. //*********************************************************************************************************
2. // Programa para la estación meteorológica Interna inalámbrica
3. // El programa recibe Temperatura, Humedad y Luminosidad por interrupción
4. // El sistema mide Temperatura y Humedad interior
5. // El enlace se realiza mediante una comunicación ASK OOK UHF sobre UART Invertido a 600bps
6. // Se muestra medición interna y externa en un LCD de 2x16
7. // Microcontrolador Silabs C8051F832
8. //*********************************************************************************************************
9. #include <reg52.h>
10. #include <REG51F800.H>
11. #include <intrins.h>
12. #include <stdio.h>
13. //*********************************************************************************************************
14. // Variables
15. //*********************************************************************************************************
16. #define HEADER 200 //Definición de valor Header para el payload
17. sbit DATA = P1^0; //Pin del bus de un hilo para el DHT11
18. static int datoInt[2]; //Variable donde se alojan los datos internos
19. static int payload[5]; //Variable donde se aloja el payload
20. static int datoExt[3]; //Variable donde se alojan los datos externos
21. sbit P0MDIN = 0xF1; //Port 0 Input Mode
22. sbit P0SKIP = 0xD4; //Port 0 Skip
23. sbit ADC0CF = 0xBC; //ADC0 Configuration
24. sbit ADC0CN = 0xE8; //ADC0 Control 0
25. sbit AD0BUSY = 0xF8; //ADC0 Busy
26. sbit ADC0L = 0xBD; //ADC0 Data Word Low Byte
27. sbit ADC0H = 0xBE; //ADC0 Data Word High Byte
28. //*********************************************************************************************************
29. // delay_us Bloqueante Micro Segundos
30. //*********************************************************************************************************
31. void delay_us(unsigned int us_count){ //Función para delay_ms de micro-segundos
32. int t=0;
33. while(us_count!=0){ //Mientras que el contador es distinto de cero
34. for(t=0;t<16;t++){ //16MIPS dividido en 16 para 1us
35. _nop_(); //Ejecuta función NOP de ensamblador
36. }
37. us_count--; //Decremento del valor de delay_ms
38. }
39. }
40. //*********************************************************************************************************
41. // delay_ms Bloqueante Mili Segundos
42. //*********************************************************************************************************
43. void delay_ms(unsigned int us_count){ //Función para delay_ms de micro-segundos
44. while(us_count!=0){ //Mientras que el contador es distinto de cero
45. delay_us(1000); //Ejecuta funcion delay_ms micro segundos
46. us_count--; //Decremento del valor de delay_ms
47. }
48. }
49. //*********************************************************************************************************
50. // Configuracion ADC pin P0.0
51. //*********************************************************************************************************
52. void configuraADC(void){
53. #define VREF 3 //Tensión de referencia interna
54. P0MDIN=0xFE; //Selecciona pin P0.0 como canal ADC
55. P0SKIP=0x01; //Decodificación Crossbar
56. ADC0CF=0xF8; //Habilita ADC 0
57. ADC0CN=0x80; //Habilita conversión en registro
58. }
59. //*********************************************************************************************************
60. // Funcion para inicializar el puerto serie 9600 @ 11.059MHz
61. //*********************************************************************************************************
62. void serialInit(void){ //Función para configurar UART
63. TMOD=0x20; //Timer 1 en modo 2 - Auto recarga para generar Baudrate
64. SCON=0x50; //Serial modo 1, 8N1
65. TH1=0xFD; //Carga el baudrate en el timer a 9600bps
66. TR1=1; //Dispara el timer
67. }
68. //*********************************************************************************************************
69. // Trama DHT11 - Según Datasheet
70. // ____ ____ ____ ___
71. // |___________| |____| |.....................................|
72. // | 18ms | |80us|80us| 5x8 bit |
73. // | PIC | | DHT11 respuesta | Fin de
74. // | request | | 2x80us, intRH, decRH, intT, decT, checksum | Trama
75. // ____ ________
76. // |________| |... 0 bit
77. // <-50us-> <-27us->
78. // ____ _________________________
79. // |________| |... 1 bit
80. // <-50us-> <---------70us---------->
81. //*********************************************************************************************************
82. unsigned int trama[5]; //Vector donde se alojan los datos
83. //*********************************************************************************************************
84. // Función de recepción de Byte
85. // Lee el valor leído en la trama y lo separa realizando shift
86. // Retorna el valor en forma de byte, es utilizado en la función recibeDato()
87. //*********************************************************************************************************
88. unsigned int recibeByte(){ //Función que recibe un Byte
89. unsigned int valorLeido = 0; //Valor de retorno de la función
90. int i=0; //Inicialización del índice
91. for(i=0; i<8; i++){ //Iteración para recepción de bits
92. valorLeido <<= 1; //Registro de desplazamiento de bits
93. while(DATA==0); //Espera a DATA = 0
94. delay_us(30); //Demora de 30us (Del Datasheet)
95. if(DATA==1){ //Pregunta si DATA = 1
96. valorLeido |= 1; //Realiza toggle del valor leído
97. }
98. while(DATA==1); //Espera a DATA = 1
99. }
100. return valorLeido; //Retorna el valor leído
101. }
102. //*********************************************************************************************************
103. // Función de recepción de dato para el DHT11
104. // Recibe los valores de temperatura y humedad (parte entera y decimales por separado)
105. // Recibe el checksum enviado por el DHT11 y lo compara con el leído en el programa
106. //*********************************************************************************************************
107. unsigned int recibeDato(){ //Funcion que recibe el Dato
108. int validacion = 0; //Variable de Validación
109. int checksum = 0; //Variable de detección de cambios de secuencia
110. int j=0; //Variable para el lazo for
111. DATA = 1; //Set DATA = 1
112. DATA = 0; //Set DATA = 0
113. delay_ms(18); //Demora de 18ms (Del Datasheet)
114. DATA = 1; //Set DATA = 1
115. delay_us(25); //Demora de 25ms (Del Datasheet)
116. validacion = DATA; //Mueve valor de DATA a Validacion
117. delay_us(80); //Espera 80us (Del Datasheet)
118. validacion = DATA; //Mueve valor de DATA a Validacion
119. if(!validacion){ //Si Validacion = 0, Error de secuencia
120. printf( "Error en Checksum \r"); //Muestra leyenda de error
121. }
122. delay_us(80); //Espera 80us (Del Datasheet)
123. for(j=0; j<5; j++){ //Lazo de carga de bytes de datos
124. trama[j] = recibeByte(); //Carga del vector de datos
125. }
126. DATA = 1; //Set DATA = 1
127. for(j=0; j<4; j++){ //Lazo de carga de bytes de verificación
128. checksum += trama[j]; //Carga de bytes de verificación
129. }
130. if(checksum == trama[4]){ //Si la secuencia de verificación es correcta
131. return 0; //Se retorna 0 y se realiza la lectura
132. }
133. }
134. //*********************************************************************************************************
135. // Lee DHT11
136. //*********************************************************************************************************
137. void leeDHT11(void){ //Funcion que lee el DHT11
138. if(recibeDato()==0){ //Consulta si hay dato en la entrada del DHT11
139. datoInt[0]=trama[2]; //Carga el valor de temperatura DHT en byte 1 del payload
140. datoInt[1]=trama[0]; //Carga el valor de humedad DHT en byte 2 del payload
141. }
142. }
143. //*********************************************************************************************************
144. // Función que realiza la lectura del sensor LDR y acondiciona el valor
145. //*********************************************************************************************************
146. int lecturaLDR(void){ //Función que realiza la lectura del ADC para el LDR
147. unsigned int adval; //Variable donde se guarda el valor del ADC
148. AD0BUSY=1; //Inicia conversión de ADC
149. while(AD0BUSY); //Espera que finalice la conversión
150. adval=ADC0L; //Lee el ADC de 0 a 511
151. return(adval); //Retorna el valor del ADC canal 0
152. }
153. //*********************************************************************************************************
154. // Función para enviar byte por puerto serie
155. //*********************************************************************************************************
156. void sendByte(unsigned char serialdata){
157. SBUF=serialdata; //Carga el dato a enviar por uart
158. while(TI==0); //Espera a la transmisión completa
159. TI=0; //Borra el flag de transmisión
160. }
161. //*********************************************************************************************************
162. // Función que realiza el parse de datos y armado del payload para enviar por UART
163. //*********************************************************************************************************
164. void enivaRF(void){ //Declaración de función para enviar datos
165. payload[0]=HEADER; //Carga el Header en byte 0 del payload
166. payload[4]=payload[1]+payload[2]+payload[3]; //Realiza suma de datos y carga en el byte 4 del payload
167. sendByte(payload[0]); //Envía el byte 0 del payload por UART
168. delay_ms(50); //Delay de espera entre bytes enviados por UART
169. sendByte(payload[1]); //Envía el byte 1 del payload por UART
170. delay_ms(50); //Delay de espera entre bytes enviados por UART
171. sendByte(payload[2]); //Envía el byte 2 del payload por UART
172. delay_ms(50); //Delay de espera entre bytes enviados por UART
173. sendByte(payload[3]); //Envía el byte 3 del payload por UART
174. delay_ms(50); //Delay de espera entre bytes enviados por UART
175. sendByte(payload[4]); //Envía el byte 4 del payload por UART
176. delay_ms(50); //Delay de espera entre bytes enviados por UART
177. printf("\r"); //Envía retorno de línea como final de payload
178. }
179. //*********************************************************************************************************
180. // Programa principal
181. // Lee la temperatura y humedad externa, lee el sensor de luminosidad, envía por RF
182. //*********************************************************************************************************
183. void main(){ //Funcion principal
184. serialInit();
185. configuraADC(); //Función que configura ADC
186. while(1){ //Loop principal infinito
187. if(recibeDato()==0){ //Consulta si hay dato en la entrada del DHT11
188. payload[1]=trama[2]; //Carga el valor de temperatura DHT en byte 1 del payload
189. payload[2]=trama[0]; //Carga el valor de humedad DHT en byte 2 del payload
190. payload[3]=lecturaLDR(); //Carga el valor de luminosidad en el byte 3 del payload
191. enivaRF(); //Llamado a la función que envía datos
192. }
193. delay_ms(2304); //Delay del timer de sleep*
194. }
195. }

Pruebas y Simulación

Por motivos de costo y disposición en el país, se ha realizado de forma paralela la prueba del proyecto en un microcontrolador Microchip de bajo costo y conseguido en la mayoría de los locales de electrónica del país. Al tratarse de un código en lenguaje C, es muy sencilla la portabilidad hacia otro microcontrolador de diferente core y arquitectura.

Las pruebas de laboratorio han sido sobre placa de prototipo tipo Protoboard o Breadboard, donde se han incluido los componentes del proyecto para las pruebas de sensores, alcance de comunicación inalámbrica, consumo de la estación externa (esta utiliza pilas primarias alcalinas).

Resultados de prueba:

Se ha logrado una distancia entre dispositivos de aproximadamente 20m indoor (con paredes y ventanas con alambre tegido), que para los fines prácticos de este proyecto ha sido satisfactorio.

Los sensores se han contrastado contra una estación meteorológica comercial “Sinometer WS-1150”, la temperatura posee un desvío de +2°C y la humedad de +8%.

El consumo en el dispositivo exterior es de 30nA en modo Sleep, 2uA en modo run y 14mA en modo TX.

La autonomía del dispositivo interior es de 30 Horas sin recargar, la carga demora 2 Horas para completar la totalidad, mediante un puerto USB de 2A.

Fotos de Prueba:

Estación Externa (DHT11, LDR, MCU, TWS433)

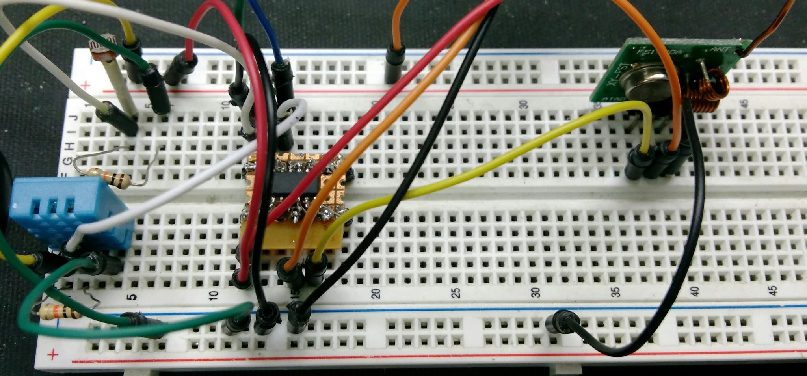
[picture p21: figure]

Estación Interna (RWS433, DHT11, LCD, MCU)

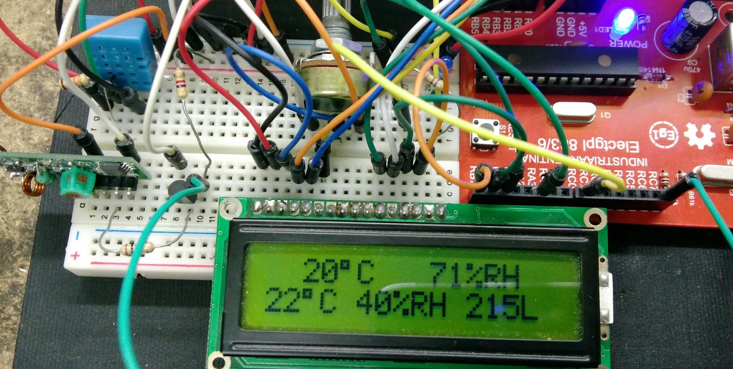
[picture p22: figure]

Medición Estación Externa en Sleep 30nA

Capturas de Simulación en Proteus:

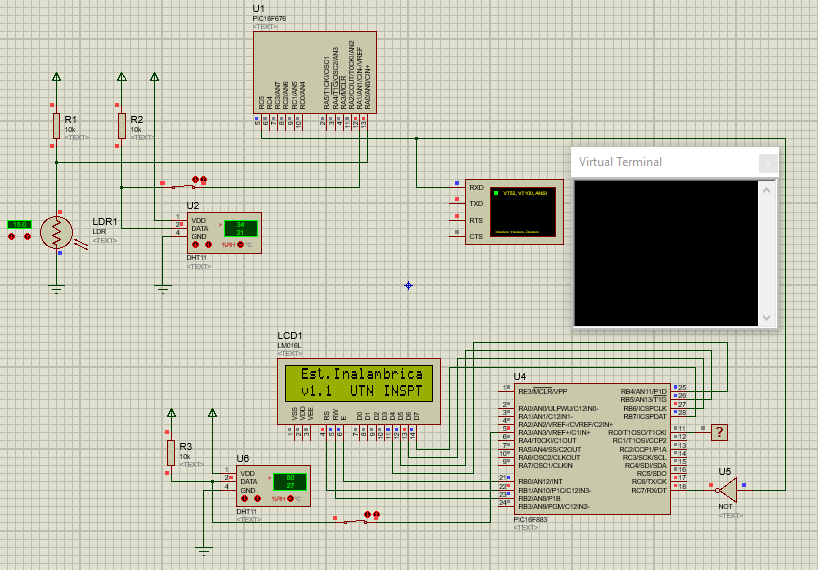
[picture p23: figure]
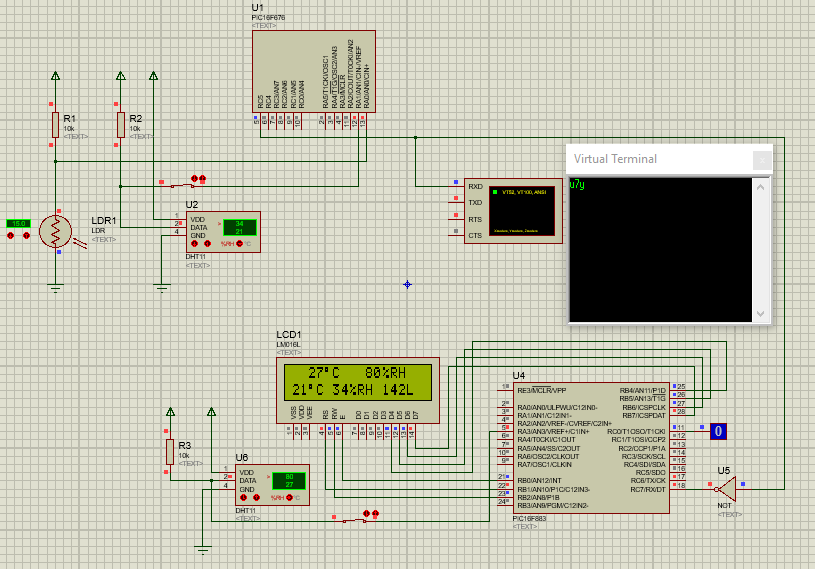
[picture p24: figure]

Capturas de Trama UART:

Se observa la trama completa (preámbulo, payload, verificación)

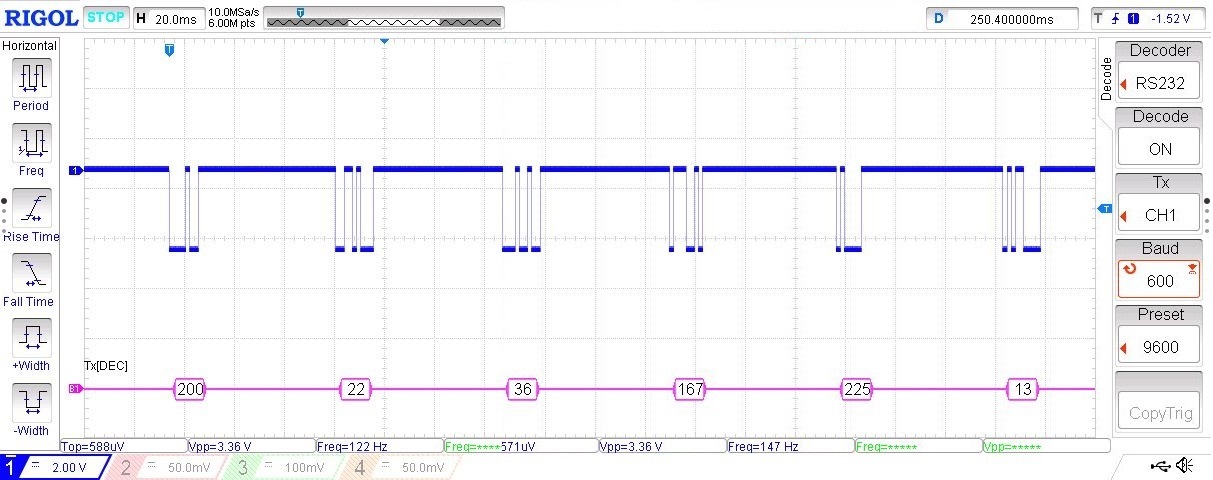
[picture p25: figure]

Se observa el Header: 200 (Establecido en el firmware), Temp: 22, Hum: 36, Lum; 167, Checksum (22+36+167): 225 y el retorno de carro (enter): 13.

Conclusiones

Se ha logrado implementar una estación meteorológica hogareña de bajo consumo y bajo costo que presenta una propuesta comercial respecto a las competidoras de mismas prestaciones.

- Se implementó el código necesario para realizar el proyecto sobre core 8051 bajo una plataforma moderna que opera en 16MHz y 16MIPS.
- Se realizó todo el tratamiento de la trama, preámbulo, payload, checksum y parseo de datos para realizar el enlace de telemetría entre los dos dispositivos.
- Se analizó la velocidad de transferencia de datos sobre UART para lograr la mejor comunicación y alcance sobre módulos de RF de bajo costo.
- Se comprobó el diseño de la antena con la ayuda de instrumental adecuado “VNA” para su correcta adaptación.

Bibliografía

[1] “Manual 8051 Keil”,

http://www.keil.com/support/man/docs/is51/

[2] “Manual Eagle”,

http://hades.mech.northwestern.edu/images/b/b4/Eagle_Manual.pdf

[3] “Norma ATEX”,

http://www.insht.es/InshtWeb/Contenidos/Normativa/GuiasTecnicas/Ficheros/ATM%C3%93SFERAS%20EXPLOSIVAS.pdf

[4] “Norma IPX3”,

http://hades.mech.northwestern.edu/images/b/b4/Eagle_Manual.pdfhttp://www.f2i2.net/documentos/lsi/rbt/guias/guia_bt_anexo_1_sep03R1.pdf

[5] “Norma IPC610”,

http://www.ipc.org/TOC/IPC-A-610E-Spanish.pdf

[6] “Datasheet DHT11”,

https://akizukidenshi.com/download/ds/aosong/DHT11.pdf

[7] “Datasheet Modulos Transmisor y Receptor RF UHF”, https://4.imimg.com/data4/AJ/NM/MY-1833510/rf-transmitter-receiver-pair-433-mhz-ask.pdf

[8] “Datasheet LDR”,

http://kennarar.vma.is/thor/v2011/vgr402/ldr.pdf

[9] “Datasheet C8051F832 Silabs”, https://www.silabs.com/documents/public/data-sheets/C8051F80x-83x.pdf

[10] “Datasheet TP4056”, https://dlnmh9ip6v2uc.cloudfront.net/datasheets/Prototyping/TP4056.pdf

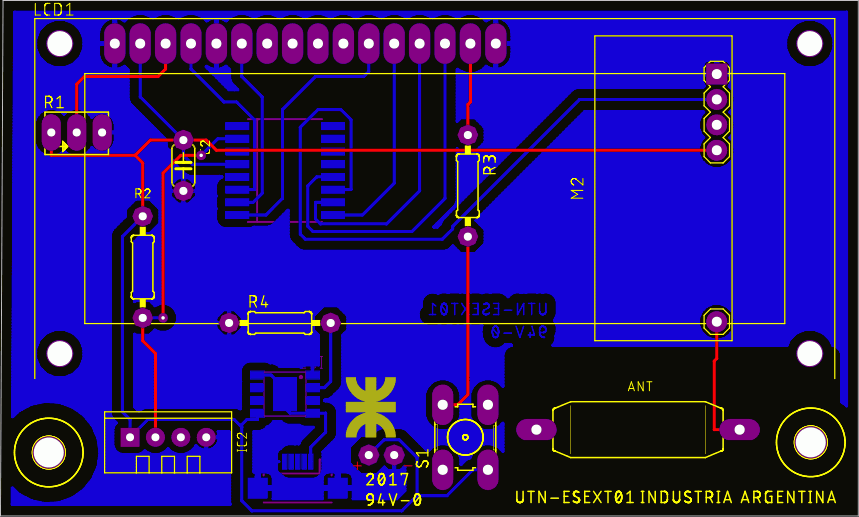
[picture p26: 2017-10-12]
Hardware Estación Interna y Externa/UTN-ESINT01/UTN-ESINT01-OVER.png

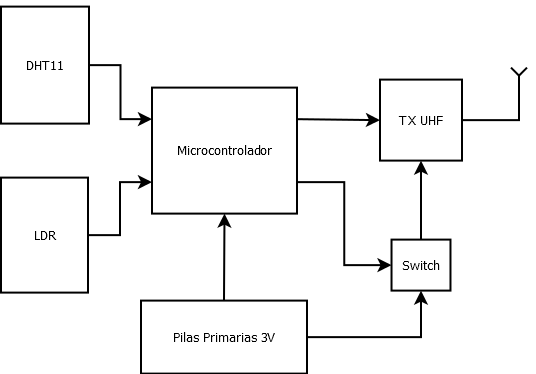
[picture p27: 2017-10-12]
Documentación/Diagramas/Diagrama Hardware Externa.png

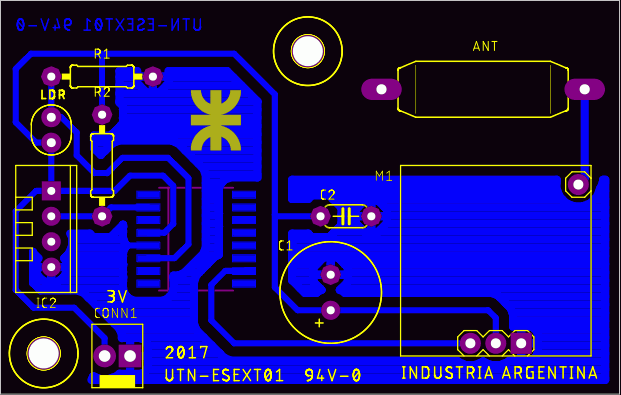
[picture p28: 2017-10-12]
Hardware Estación Interna y Externa/UTN-ESEXT01/UTN-ESEXT01-OVER.png

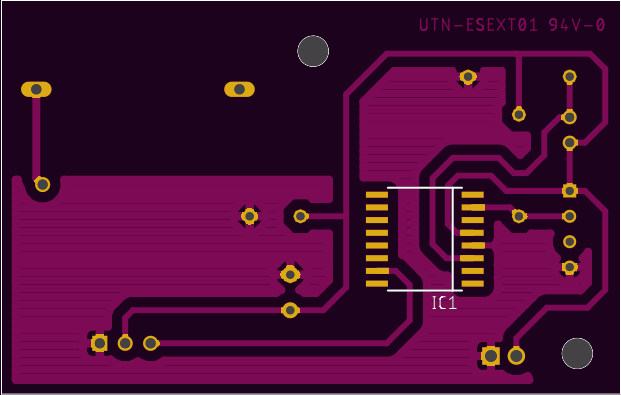
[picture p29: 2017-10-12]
Hardware Estación Interna y Externa/UTN-ESEXT01/UTN-ESEXT01-BOTTOM.png

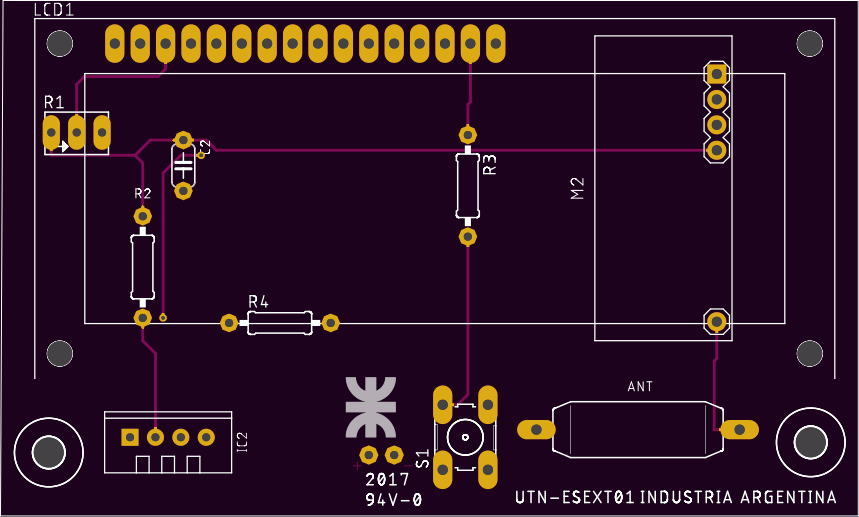
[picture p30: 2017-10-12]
Hardware Estación Interna y Externa/UTN-ESINT01/UTN-ESINT01-TOP.png

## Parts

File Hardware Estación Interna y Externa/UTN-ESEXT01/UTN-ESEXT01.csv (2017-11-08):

Qty | Value | Device | Package | Parts | Description
1 | 100n | C-EU050-024X044 | C050-024X044 | C2 | CAPACITOR, European symbol
1 | 10k | PHOTOCELLONB | ON_BOARD | LDR | Photo Resitor
2 | 10k | R-US_0207/10 | 0207/10 | R1, R2 | RESISTOR, American symbol
1 | 433 HELIX | SMSC20 | SMSC20 | ANT | INDUCTOR
1 | 433.92 ASK | WIRELESS-XY-FST | WIRELESS-XY-FST | M1 | RF Wireless XY-FST Transmitter
1 | 470u | CPOL-EUE3.5-10 | E3,5-10 | C1 | POLARIZED CAPACITOR, European symbol
1 | C8051F832 | C8051F832 | SOIC16R | IC1 | 8kB ILP Flash MCU Family
1 | DHT11 | TEMP-HUM-SENSOR-DHT11 | TEMP-HUM-SENSOR-DHT11 | IC2 | DHT11 - digital humidity & temperature sensor
1 | KK2VSQ | KK2VSQ | KK-V-2-SQ | CONN1 | Molex KK
1 | UTN_LOGO | UTN_LOGO | UTN_LOGO | U$3

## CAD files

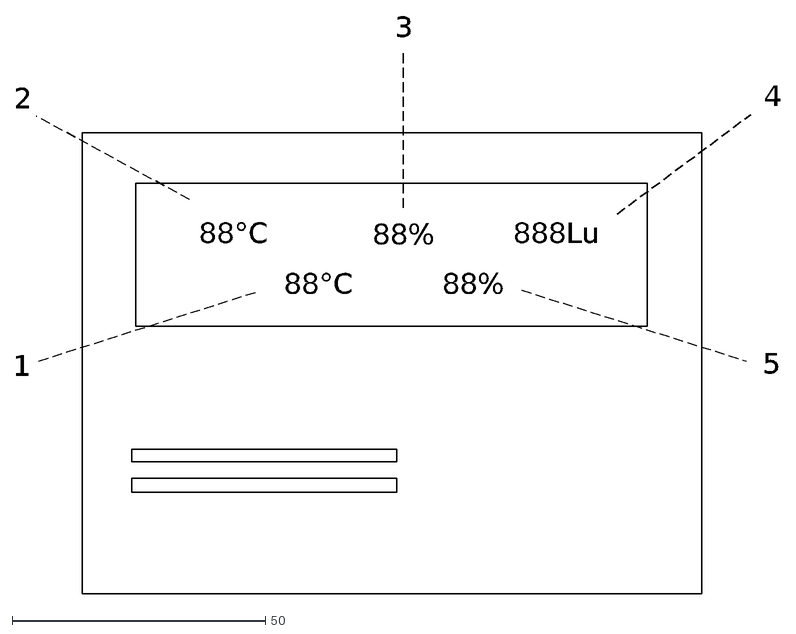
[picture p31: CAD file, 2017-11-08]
Documentación/Imagenes/plano ejemplo display.dxf
88°C
88%
888Lu
4
5
1
2
3

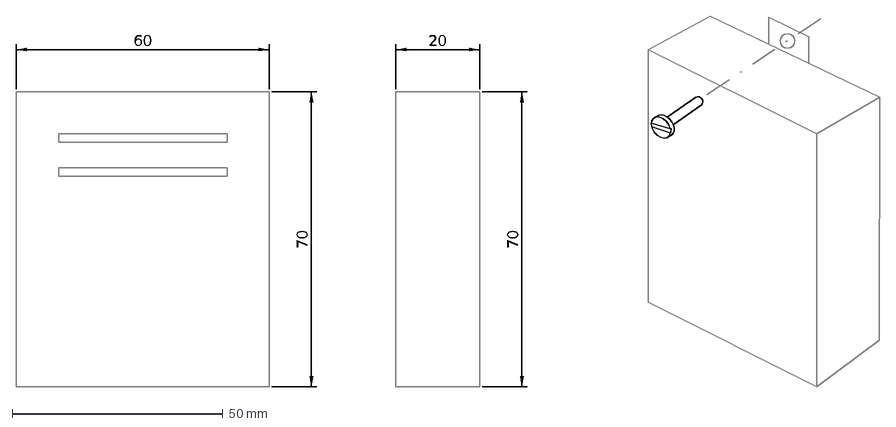
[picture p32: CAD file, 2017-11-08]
Documentación/Imagenes/plano sensor externo.dxf
60
70
20

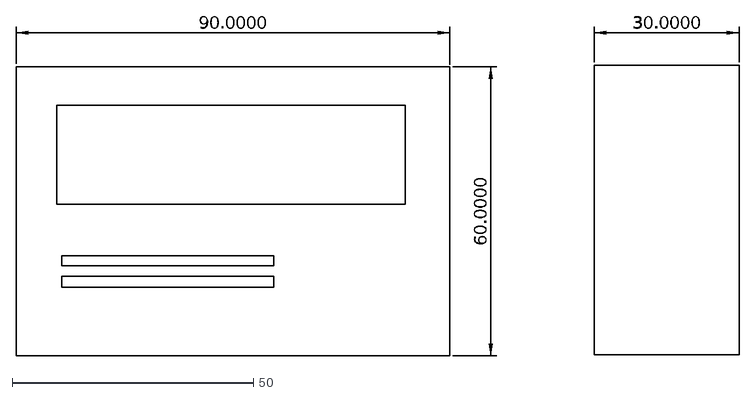
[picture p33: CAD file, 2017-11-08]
Documentación/Imagenes/plano sensor interno.dxf
90.0000
60.0000
30.0000

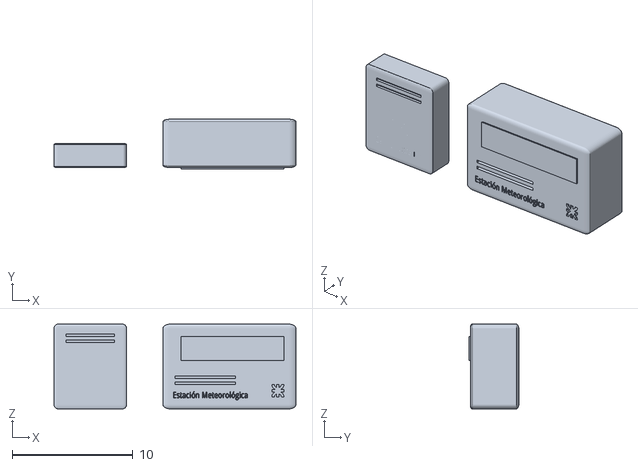
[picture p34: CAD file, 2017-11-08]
Documentación/Imagenes/Estación Meteorológica.stl
20.0 x 4.10 x 7.00

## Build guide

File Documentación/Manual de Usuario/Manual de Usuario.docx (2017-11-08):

Estación Meteorológica Inalámbrica

mod.UTN1703


Manual de Usuario

Guía de Instalación

Índice:

1. Contenido de la Caja
2. Características
3. Instalación
  3.1. Instalar Baterías
  3.2. Montaje
4. Visión General del LCD
5. Problemas y Soluciones
6. Especificaciones Técnicas

ATENCIÓN: Este equipo no dispone de protección ATEX, por lo que no debe ser usado en atmósferas potencialmente explosivas (polvo, gases inflamables).

Comuniquese a nuestro service al: 0-600-UTN-INSPT

Visite nuestra web para mas informacion: www.estacionutn.com.ar

1. Contenido de la Caja

Estación Base (1 unidad)

Sensor Exterior (1 unidad)

Manual de Instrucciones (1 unidad)

Pilas AA Alcalinas (2 unidades)

Cable USB - microUSB (1 unidad)

2. Características

Humedad Exterior e Interior (% RH)

Temperatura Exterior e Interior (°C)

Luminosidad Exterior (% de cantidad de luz)

Comunicación Inalámbrica entre Base y Sensor Exterior

Autonomía de las pilas AA del Sensor Exterior de 2 Años

Base recargable mediante USB

3. Instalación
  3.1. Instalar Baterías

ANTES DE INSTALAR LAS PILAS EN EL SENSOR EXTERNO ASEGÚRESE DE QUE LAS MISMAS SON ALCALINAS Y SE COLOCAN EN LA POSICIÓN CORRECTA. NO UTILICE PILAS GASTADAS. NO RECARGUE LAS PILAS ALCALINAS.

A. En la Base

Conecte el cable USB - microUSB en la estación Base y aguarde a que el LED indicador se encienda indicando que se encuentra cargando la batería interna.

Una vez que el nivel de la batería interna alcanza el mínimo umbral, se encenderá la estación mostrando un mensaje de saludo y comenzará la medición.

NOTA: Si aún no se encuentra encendido el sensor exterior, mostrará guion medio en los valores exteriores ( 0°C, 0%RH, 0%L).

B. En el sensor Exterior

Introducir las pilas AA de forma correcta en el sensor exterior.

El sensor Exterior comenzará a transmitir la datos de forma automática, la estación interior actualizará sus valores según el cambio de parámetros medidos en el exterior.

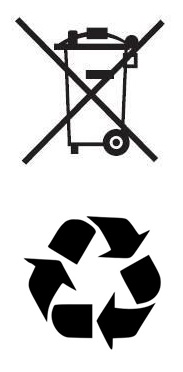
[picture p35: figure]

| Cuando las pilas necesiten ser reemplazadas, participe por la conservación del medio ambiente mediante la disposición adecuada de baterías y acumuladores en los puntos de disposición designados por su país. Nunca arroje las baterías al fuego, ya que esto puede provocar una explosión, riesgo de incendio o fugas de productos químicos peligrosos y humos.

  3.2. Montaje
A. Del sensor Exterior

El montaje puede ser sobre mesa o bien con un tornillo de fijación o anclaje en pared o poste.

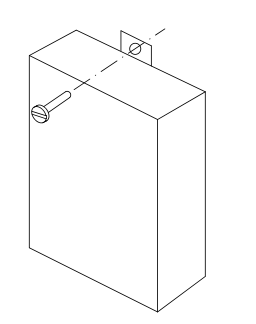
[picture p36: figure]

B. De la Base

Montaje horizontal sobre mesa, no requiere de ningún tipo de anclaje o fijación.

4. Visión General del LCD

La siguiente ilustración mostrará las distintas secciones de pantalla LCD.

(cada pantalla cambia automáticamente cada 3 segundos)


| 1) Temperatura Interior 2) Humedad Interior 3) Temperatura Exterior 4) Humedad Exterior 5) Cantidad de Luz Exterior

5. Problemas y Soluciones

Problema | Solución
No se actualizan los datos del sensor exterior. | Verificar la carga de las pilas y la correcta ubicación de las mismas.
No se actualizan los datos del sensor exterior. | Reducir la distancia entre el sensor externo y la estación base.
El sensor se encuentra a una distancia corta pero aún no se actualizan los datos. | Verificar el material de construcción de la edificación, ya que puede funcionar como blindaje para las comunicaciones.
No se enciende el LCD en la estación base. | Verificar que la misma se encuentre cargada. Conectar el cable USB - microUSB y cargar la misma.
Temperatura, humedad, luminosidad son incorrectos | Verificar la carga de las pilas en el sensor exterior.

6. Especificaciones Técnicas

Rango de temperatura 0-50°c (precisión ±2°c)
Rango de humedad 20-90%RH (precisión ±5％)

Rango de luminosidad 0-100% (precisión ±20％)

Rango de trabajo hasta 20m
Frecuencia de trabajo 433MHz

Batería de sensor 2xAA Alcalina - Vida útil de 2 años

Batería de cuerpo 1x18650 - Vida útil Recargable via USB

Medidas cuerpo 113x67x27.5mm
Sensor 91x70x32.5mm

Gabinete exterior IPX3

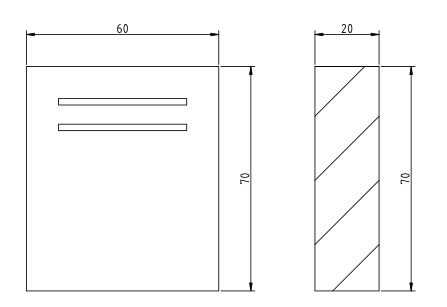
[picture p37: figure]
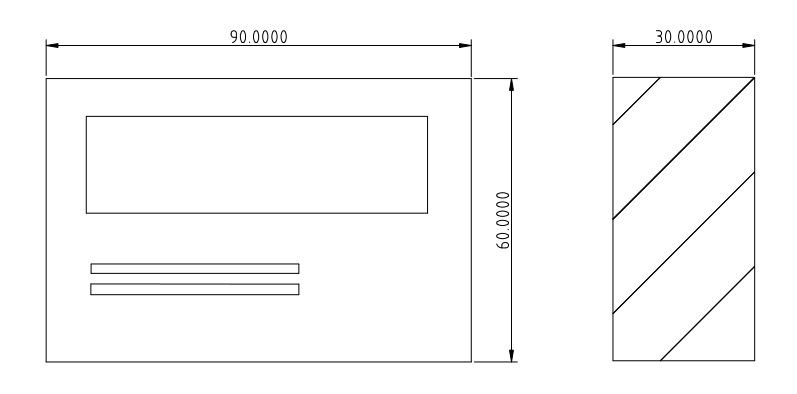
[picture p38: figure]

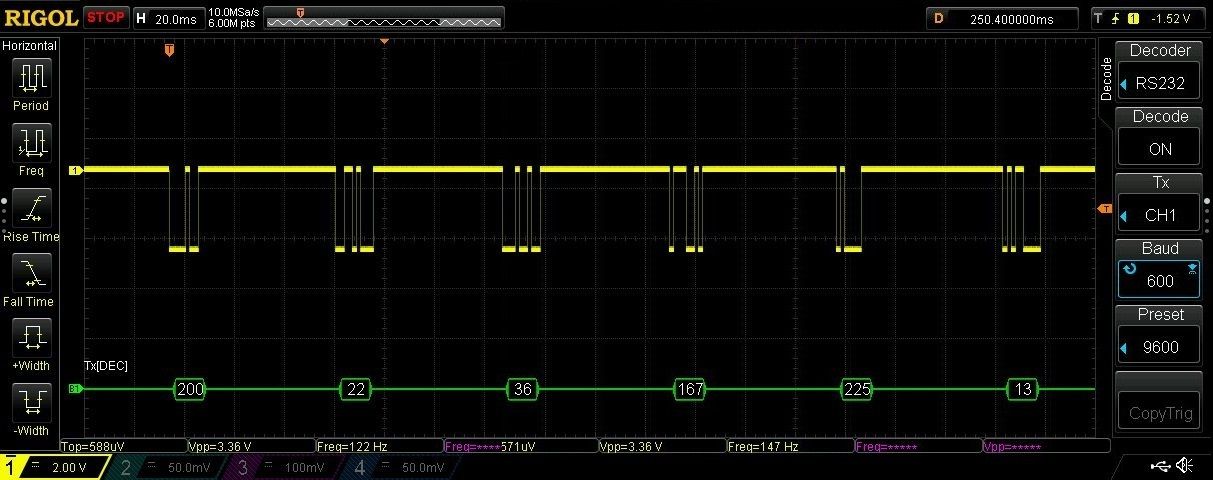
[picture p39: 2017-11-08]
Documentación/Imagenes/DS1Z_QuickPrintSpan.jpg

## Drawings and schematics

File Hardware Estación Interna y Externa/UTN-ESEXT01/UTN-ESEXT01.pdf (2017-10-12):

# GND GND ¹⁰⁰n

A

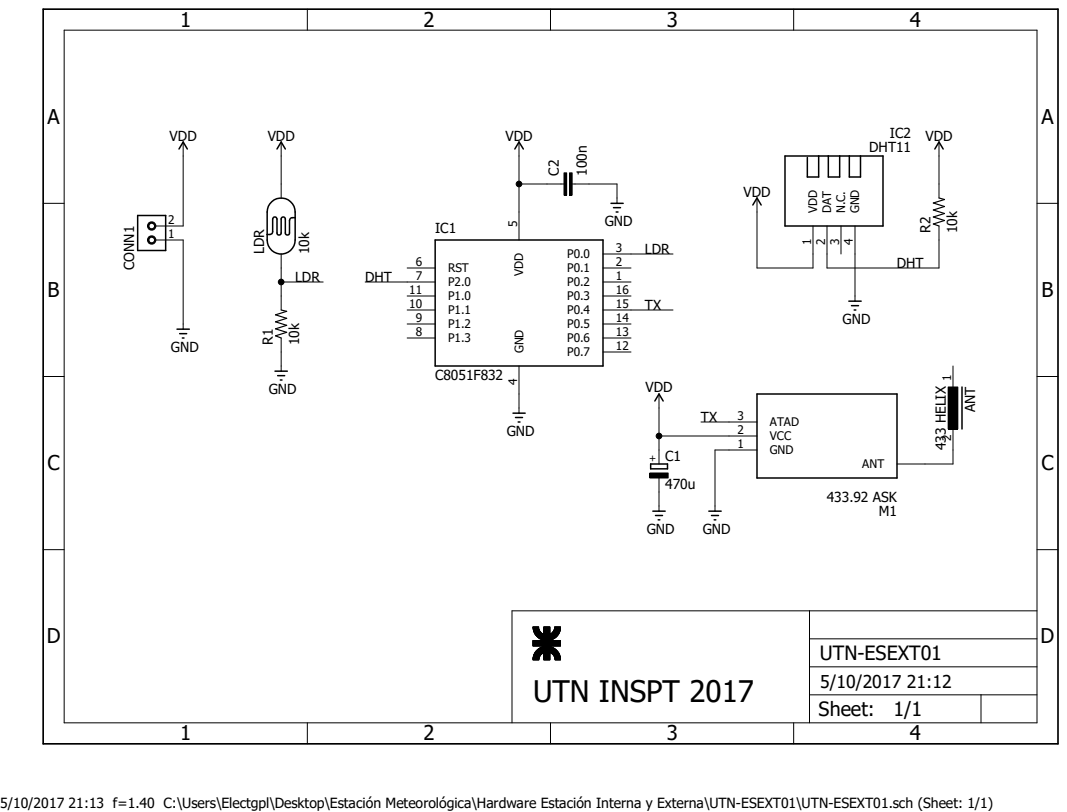
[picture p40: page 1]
433.92 ASK ¹⁰k 10k; GND; VDD; 433 HELIX; 1 DAT; 2 N.C. 3 GND; IC2 DHT11; ANT; GND 1; VCC 2; ATAD 3; M1 LDR R¹; ANT 2 1 CONN¹; 12 VDD; 5 GND; 4 P2.0 7 RST 6; LDR; DHT; UTN-ESEXT01 5/10/2017 21:12

UTN INSPT 2017

Sheet: 1/1

5/10/2017 21:13 f=1.40 C:\Users\Electgpl\Desktop\Estación Meteorológica\Hardware Estación Interna y Externa\UTN-ESEXT01\UTN-ESEXT01.sch (Sheet: 1/1)

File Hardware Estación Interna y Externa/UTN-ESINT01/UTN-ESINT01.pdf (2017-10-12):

# VDD 10k

A

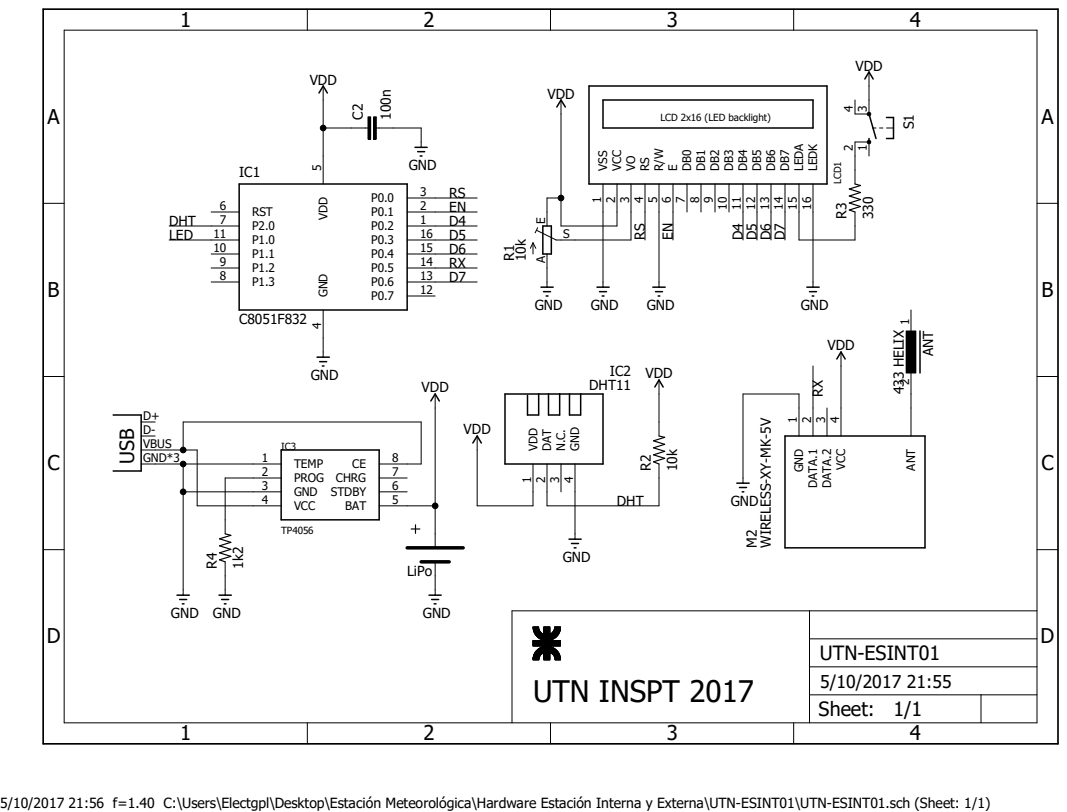
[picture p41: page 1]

VDD WIRELESS⁻XY⁻MK⁻5V TP4056
VDD

LCD 2x16 (LED backlight) USB

5/10/2017 21:56 f=1.40 C:\Users\Electgpl\Desktop\Estación Meteorológica\Hardware Estación Interna y Externa\UTN-ESINT01\UTN-ESINT01.sch (Sheet: 1/1) ¹⁰k

UTN INSPT 2017

Sheet: 1/1

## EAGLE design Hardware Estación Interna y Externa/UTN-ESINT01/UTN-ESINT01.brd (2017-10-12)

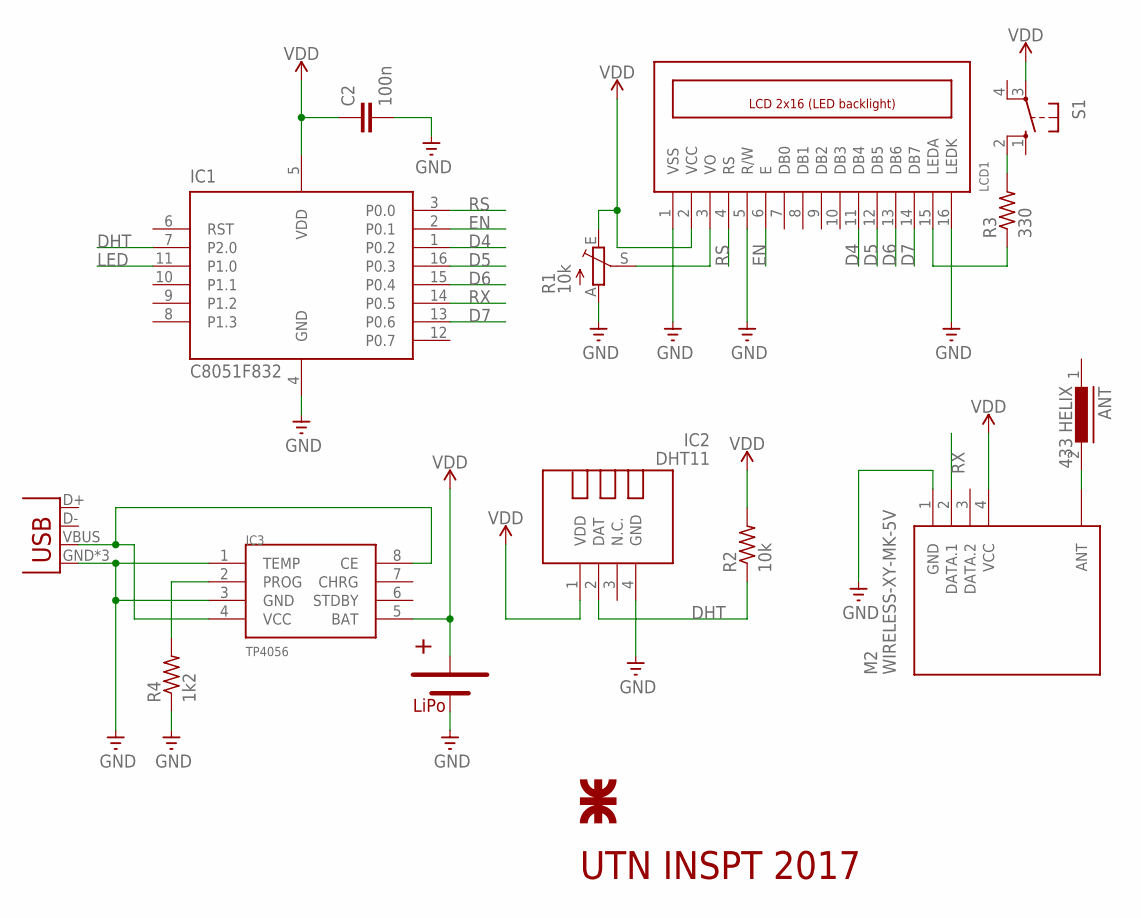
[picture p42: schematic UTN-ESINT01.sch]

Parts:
ANT: 433 HELIX; SMSC20
C2: 100n; C050-024X044
IC1: C8051F832; SOIC16R
IC2: DHT11; TEMP-HUM-SENSOR-DHT11
IC3: TP4056; SOP-8
LCD1: LCD_2X16_SIL; HY-1602F
M2: WIRELESS-XY-MK-5V
R1: 10k; B64Y
R2: 10k; 0207/10
R3: 330; 0207/10
R4: 1k2; 0207/10
S1: 10-XX; B3F-10XX
U$3: UTN_LOGO
U$4: LiPo; BATTERYPAD
X1: USB-MICROB

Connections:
D4: IC1.1 (P0.2), LCD1.11 (DB4)
D5: IC1.16 (P0.3), LCD1.12 (DB5)
D6: IC1.15 (P0.4), LCD1.13 (DB6)
D7: IC1.13 (P0.6), LCD1.14 (DB7)
DHT: IC1.7 (P2.0), IC2.2 (DAT), R2.1
EN: IC1.2 (P0.1), LCD1.6 (E)
GND: C2.2, IC1.4 (GND), IC2.4 (GND), IC3.1 (TEMP), IC3.3 (GND), LCD1.1 (VSS), LCD1.5 (R/W), LCD1.16 (LEDK), M2.1 (GND), R1.A, R4.1, U$4.-VE, X1.GND, X1.MT1 (GND), X1.MT2 (GND)
LED: IC1.11 (P1.0)
unnamed: ANT.2, M2.ANT
unnamed: IC3.4 (VCC), IC3.8 (CE), X1.VBUS
unnamed: LCD1.3 (VO), R1.S
unnamed: LCD1.15 (LEDA), R3.1
unnamed: R3.2, S1.2 (S1)
unnamed: IC3.2 (PROG), R4.2
RS: IC1.3 (P0.0), LCD1.4 (RS)
RX: IC1.14 (P0.5), M2.2 (DATA.1)
VDD: C2.1, IC1.5 (VDD), IC2.1 (VDD), IC3.5 (BAT), LCD1.2 (VCC), M2.4 (VCC), R1.E, R2.2, S1.3, U$4.+VE

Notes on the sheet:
UTN INSPT 2017
LiPo

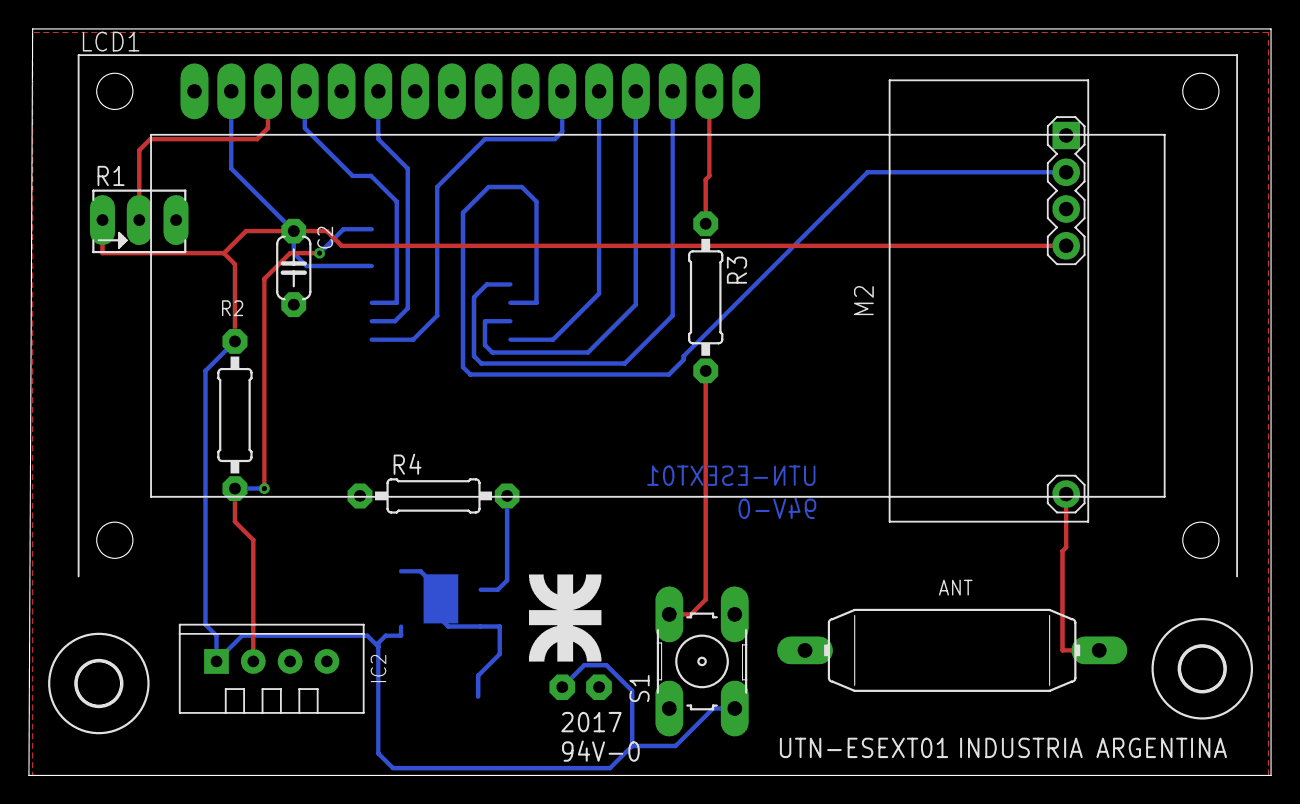
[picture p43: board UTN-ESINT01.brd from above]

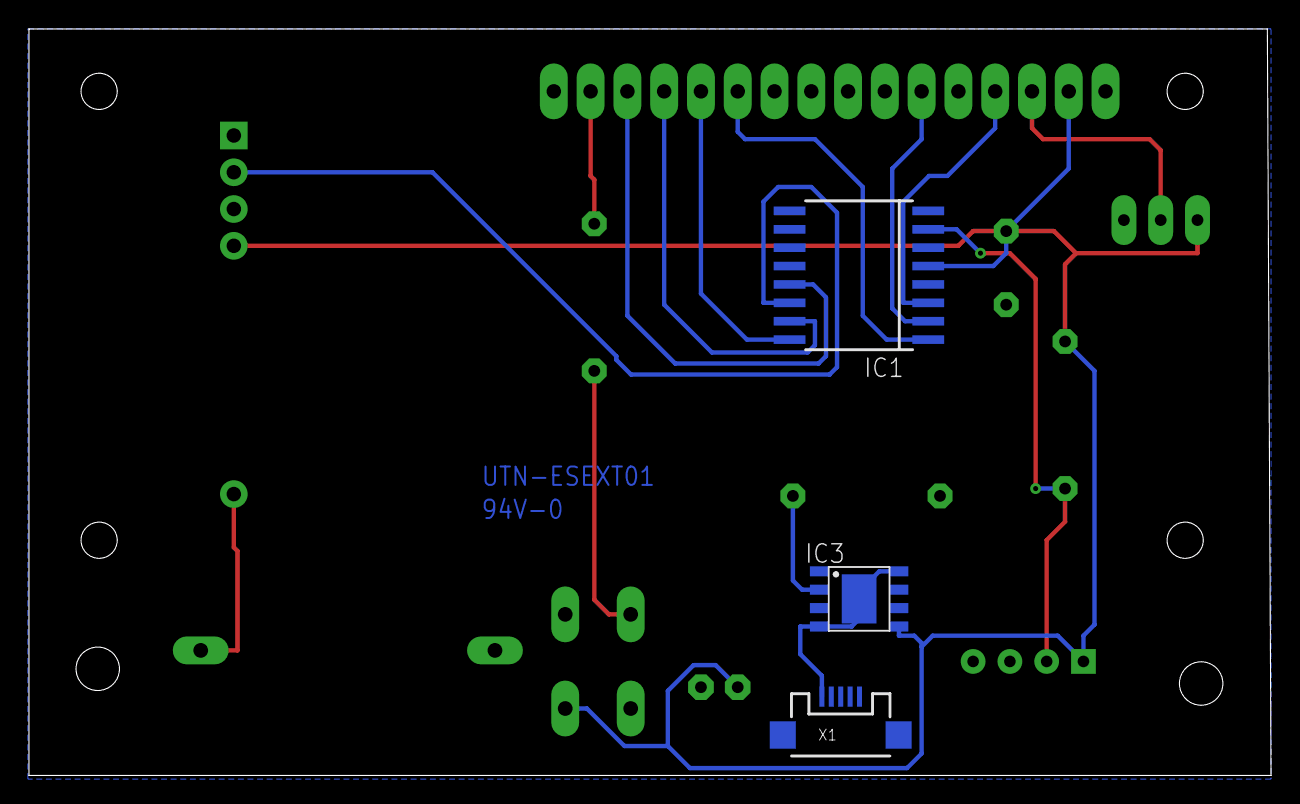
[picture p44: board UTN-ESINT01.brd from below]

Board: 2 copper layers, 85.8 x 51.6 mm, 17 parts (3 on the bottom side), 16 nets.

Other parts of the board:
U$1, U$2: 3,0

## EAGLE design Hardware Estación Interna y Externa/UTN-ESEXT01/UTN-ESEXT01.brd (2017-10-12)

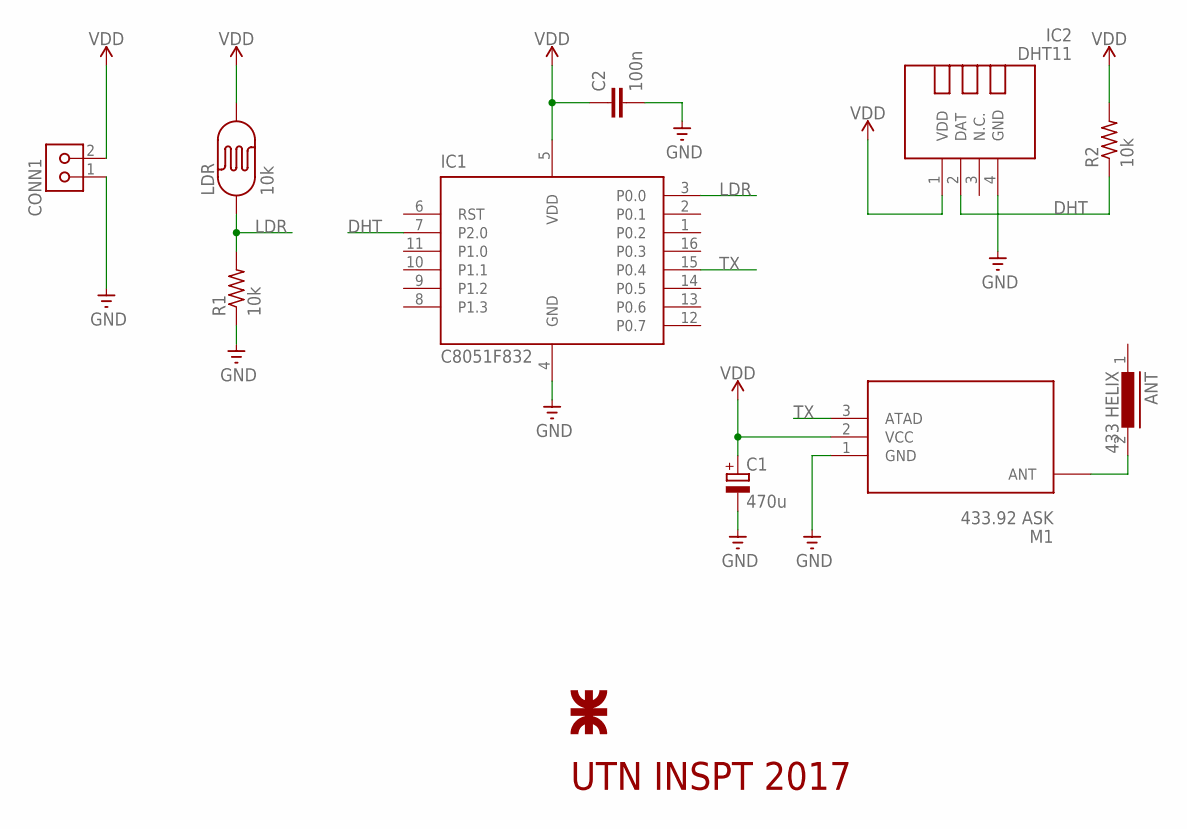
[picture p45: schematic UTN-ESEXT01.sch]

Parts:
ANT: 433 HELIX; SMSC20
C1: 470u; E3,5-10
C2: 100n; C050-024X044
CONN1: KK2VSQ; KK-V-2-SQ
IC1: C8051F832; SOIC16R
IC2: DHT11; TEMP-HUM-SENSOR-DHT11
LDR: 10k; ON_BOARD
M1: 433.92 ASK; WIRELESS-XY-FST
R1, R2: 10k; 0207/10
U$3: UTN_LOGO

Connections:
DHT: IC1.7 (P2.0), IC2.2 (DAT), R2.1
GND: C1.-, C2.2, CONN1.1, IC1.4 (GND), IC2.4 (GND), M1.1 (GND), R1.1
LDR: IC1.3 (P0.0), LDR.1, R1.2
unnamed: ANT.2, M1.ANT
TX: IC1.15 (P0.4), M1.3 (ATAD)
VDD: C1.+, C2.1, CONN1.2, IC1.5 (VDD), IC2.1 (VDD), LDR.2, M1.2 (VCC), R2.2

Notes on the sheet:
UTN INSPT 2017

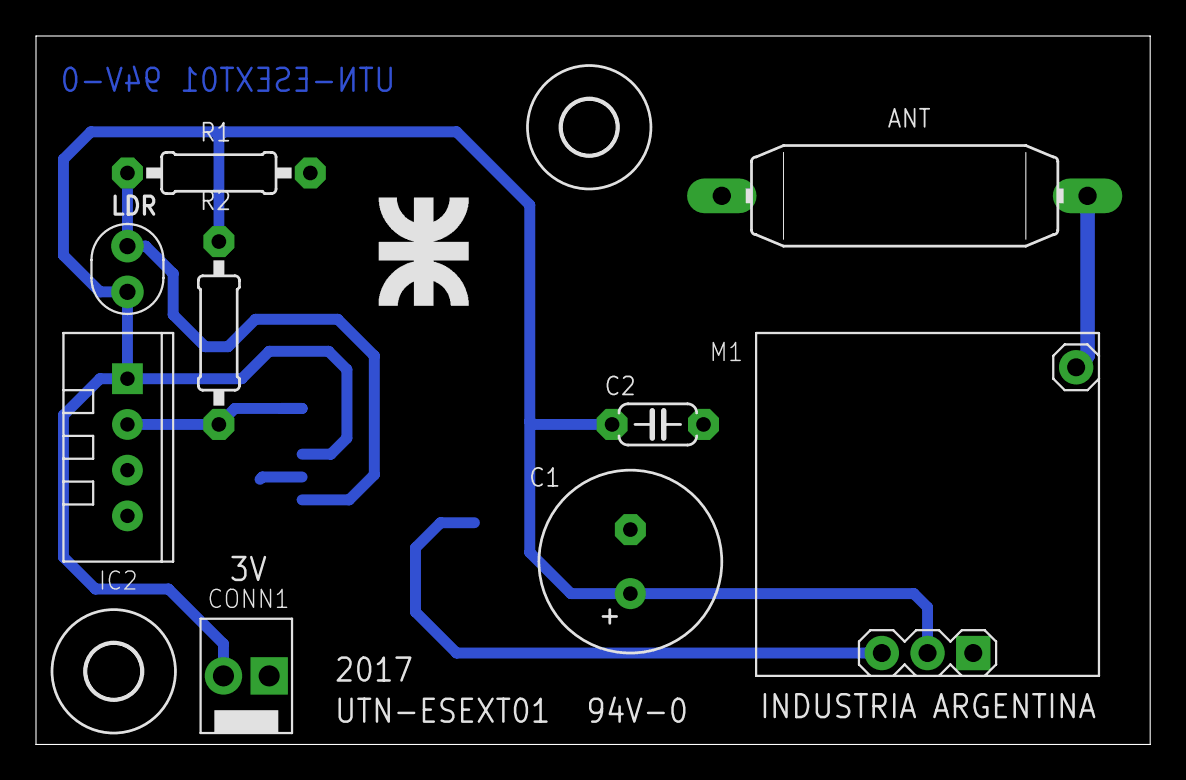
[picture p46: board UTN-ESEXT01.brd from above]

Board: 2 copper layers, 61.9 x 39.4 mm, 13 parts (1 on the bottom side), 6 nets.

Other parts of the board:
U$1, U$2: 3,0

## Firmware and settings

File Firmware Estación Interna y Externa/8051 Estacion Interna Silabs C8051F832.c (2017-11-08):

//*********************************************************************************************************
// Programa para la estacion meteorologica Interna inalámbrica
// El programa recibe Temperatura, Humedad y Luminosidad por interrupcion
// El sistema mide Temperatura y Humedad interior
// El enlace se realiza mediante una comunicacion ASK OOK UHF sobre UART Invertido a 600bps
// Se muestra medicion interna y externa en un LCD de 2x16
// Microcontrolador Silabs C8051F832
//*********************************************************************************************************
//#include <REG51F800.H>                                     //Se comenta segun compilador
#include <reg52.h>
#include <intrins.h>
#include <stdio.h>
//*********************************************************************************************************
// Variables
//*********************************************************************************************************
#define HEADER 200                                           //Definicion de valor Header para el payload
sbit DATA = P1^0;                                            //Pin del bus de un hilo para el DHT11
static int datoInt[2];                                       //Variable donde se alojan los datos internos
static int payload[5];                                       //Variable donde se aloja el payload
static int datoExt[3];                                       //Variable donde se alojan los datos externos
//*********************************************************************************************************
// Configuracion de pines del LCD
//*********************************************************************************************************
extern bit RS;                                               //Definicion de pines                                                                   
extern bit EN;                                               //Definicion de pines                            
extern bit D4;                                               //Definicion de pines 
extern bit D5;                                               //Definicion de pines 
extern bit D6;                                               //Definicion de pines 
extern bit D7;                                               //Definicion de pines 
sbit RS = P2^0;                                              //Definicion de pines                                                                    
sbit EN = P2^1;                                              //Definicion de pines                            
sbit D4 = P2^4;                                              //Definicion de pines
sbit D5 = P2^5;                                              //Definicion de pines
sbit D6 = P2^6;                                              //Definicion de pines
sbit D7 = P2^7;                                              //Definicion de pines
//*********************************************************************************************************
// delay_us Bloqueante Micro Segundos
//*********************************************************************************************************
void delay_us(unsigned int us_count){                        //Funcion para delay_ms de micro-segundos
   int t=0;
   while(us_count!=0){                                       //Mientras que el contador es distinto de cero
      for(t=0;t<16;t++){                                     //16MIPS dividido en 16 para 1us
         _nop_();                                            //Ejecuta funcion NOP de ensamblador
      }
      us_count--;                                            //Decremento del valor de delay_ms
   }
}
//*********************************************************************************************************
// delay_ms Bloqueante Mili Segundos
//*********************************************************************************************************
void delay_ms(unsigned int us_count){                        //Funcion para delay_ms de micro-segundos
   while(us_count!=0){                                       //Mientras que el contador es distinto de cero
      delay_us(1000);                                        //Ejecuta funcion delay_ms micro segundos
      us_count--;                                            //Decremento del valor de delay_ms
   }
}
//*********************************************************************************************************
// Funcion que escribe en puerto
//*********************************************************************************************************
void lcdPort(char a){                                        //Funcion para escribir el puerto en 4bit
    if(a&1) D4=1;                                            //Evalua si a AND 0001, D4 a HIGH
      else  D4=0;                                            //Caso contrario D4 a LOW
    if(a&2) D5=1;                                            //Evalua si a AND 0010, D5 a HIGH 
      else  D5=0;                                            //Caso contrario D5 a LOW
    if(a&4) D6=1;                                            //Evalua si a AND 0100, D6 a HIGH 
      else  D6=0;                                            //Caso contrario D6 a LOW
    if(a&8) D7=1;                                            //Evalua si a AND 1000, D7 a HIGH 
      else  D7=0;                                            //Caso contrario D7 a LOW
 }
 //*********************************************************************************************************
 // Funcion que envia comando
 //*********************************************************************************************************
 void lcdCmd(char a){                                        //Funcion para realizar comandos en LCD
    RS=0;                                                    //Control RS a LOW
    lcdPort(a);                                              //Llamado a lcdPort
    EN=1;                                                    //Control EN a HIGH
    delay_ms(5);                                             //Espera de 5ms
    EN=0;                                                    //Control EN a LOW
 }
 //*********************************************************************************************************
 // Borrado de LCD
 //*********************************************************************************************************
 lcdClear(){                                                 //Funcion para borrar el LCD
    lcdCmd(0);                                               //Se envia comando LOW
    lcdCmd(1);                                               //Se envia comando HIGH
 }
 //*********************************************************************************************************
 // Funcion para ir a la posicion especifica
 //*********************************************************************************************************
 void lcdGotoxy(char b, char a){                             //Funcion para posicionar el cursor
    char temp,z,y;                                           //Declaracion de variables
    if(a==1){                                                //Si se encuentra en renglon 1
      temp=0x80+b;                                           //Se incremena la columna
       z=temp>>4;                                            //Se realiza el desplazamiento
       y=temp&0x0F;                                          //Se aplica la mascara de bits
       lcdCmd(z);                                            //Envia comandos
       lcdCmd(y);                                            //Envia comandos
    }else{                                                   //Si no esta en renglon 1
       if(a==2){                                             //Si se encuentra en renglon 2
          temp=0xC0+b;                                       //Se incrementa la columna
          z=temp>>4;                                         //Se realiza el desplazamiento
          y=temp&0x0F;                                       //Se realiza la mascara
          lcdCmd(z);                                         //Envia comandos
          lcdCmd(y);                                         //Envia comandos
       }
    }		
 }
 //*********************************************************************************************************
 // Inicializa LCD
 //*********************************************************************************************************
 void lcdInit(){                                             //Funcion para inicializar el LCD
    lcdPort(0x00);                                           //Se envia 0000 0000
    delay_ms(200);                                           //Delay de 200ms
    lcdCmd(0x03);                                            //Se envia 0000 0011
    delay_ms(50);                                            //Delay de 50ms
    lcdCmd(0x03);                                            //Se envia 0000 0011
    delay_ms(110);                                           //Delay de 110ms
    lcdCmd(0x03);                                            //Se envia 0000 0011
    lcdCmd(0x02);                                            //Se envia 0000 0010
    lcdCmd(0x02);                                            //Se envia 0000 0010
    lcdCmd(0x08);                                            //Se envia 0000 1000
    lcdCmd(0x00);                                            //Se envia 0000 0000 
    lcdCmd(0x0C);                                            //Se envia 0000 1100
    lcdCmd(0x00);                                            //Se envia 0000 0000
    lcdCmd(0x06);                                            //Se envia 0000 0110
 }
 //*********************************************************************************************************
 // Funcion para escribir caracter
 //*********************************************************************************************************
 void lcdWriteChar(char a){                                  //Funcion para escribir un caracter
    char temp,y;                                             //Declaracion de variables
    temp=a&0x0F;                                             //Se realiza la mascara de bits 0000 1111
    y=a&0xF0;                                                //Se realiza la mascara de bits 0000 1111
    RS=1;                                                    //Control RS a HIGH
    lcdPort(y>>4);                                           //Se desplaza 4 lugares a la derecha
    EN=1;                                                    //Control EN a HIGH
    delay_ms(5);                                             //Delay de 5ms
    EN=0;                                                    //Control EN a LOW
    lcdPort(temp);                                           //Se envia el valor
    EN=1;                                                    //Control EN a HIGH
    delay_ms(5);                                             //Delay de 5ms
    EN=0;                                                    //Control EN a LOW
 }
 //*********************************************************************************************************
 // Funcion para escribir string
 //*********************************************************************************************************
 void lcdWriteString(char *a){                               //Funcion para escribir string
    int i;                                                   //Declaracion de variables
    for(i=0;a[i]!='\0';i++)                                  //Iteracion de caracteres hasta el NULL
       lcdWriteChar(a[i]);                                   //Se carga cada caracter para formar string
 }
//*********************************************************************************************************
// Funcion ITOA para convertir entero en ascii
//*********************************************************************************************************
char *itoa(long int num, char *s){                           //Funcion ITOA (Entero to ASCII)
   unsigned long int temp=1;                                 //Declaración de valor temporal
   unsigned int i, cnt=0;                                    //Declaración de indices y contadores
   char c;                                                   //Declaración de variable de carácter de salida
   while(temp>0){                                            //Rutina de Conversión (Queda invertida)
      temp=(num/10);                                         //Conversión de carácter a carácter
      s[cnt]=(num%10)+'0';                                   //utilizando divisiones y resto
      if(s[cnt]>0x39)                                        //sumando el offset de la tabla ASCII
         s[cnt]+=0x7;
      cnt++;
      num=temp;
   }
   for(i=0;i<(int)(cnt/2);i++){                              //Rutina para invertir el numero convertido
      c=s[i];                                                //Intercambio de variables
      s[i]=s[cnt-i-1];
      s[cnt-i-1]=c;
   }
   s[cnt]='\0';                                              //Carácter nulo, fin de la conversión ITOA
   return s;                                                 //Retorno del valor ASCII
}
//*********************************************************************************************************
// Funcion para inicializar el puerto serie 9600 @ 11.059MHz
//*********************************************************************************************************
void serialInit(void){                                       //Funcion para configurar UART
    TMOD=0x20;                                               //Timer 1 en modo 2 - Auto recarga para generar Baudrate
    SCON=0x50;                                               //Serial modo 1, 8bit de dato, 1bit de start, 1bit de stop
    TH1=0xFD;                                                //Carga el baudrate en el timer a 9600bps
    TR1=1;                                                   //Dispara el timer
 }
 //*********************************************************************************************************
 // Función Interrupción UART que realiza el parse de datos, validación de Header y Checksum
 // Si validación y Checksum son validos, carga el vector DATO para ser utilizado
 //*********************************************************************************************************
 char i=0;                                                   //Variable para el contador de bytes de entrada
 void serial_ISR(void) interrupt 4{                          //Función de servicio de interrupción
      if(RI==1){                                             //Si hay dato pendiente en UART
       payload[i++]=SBUF;                                    //Guarda byte de entrada en payload. incrementa indice
       RI=0;                                                 //Pone a cero el flag
    }                                      
    if(i>5){                                                 //Si el indice es mayor que 5 se asume que se completa el payload
       if(payload[0]==HEADER){                               //Validación que el Header sea 200 (seteado en el transmisor)
          if(payload[1]+payload[2]+payload[3]-payload[4]==0){//Validación de checksum, si datos leídos son igual a checksum
             datoExt[0]=payload[1];                          //Cargamos los datos en el vector
             datoExt[1]=payload[2];                          //Cargamos los datos en el vector
             datoExt[2]=payload[3];                          //Cargamos los datos en el vector
          }
       }
       i=0;                                                  //Una vez que se completan los 5 bytes, se reinicia el contador
    }	 
    RI=0;                                                    //Pone a cero el flag 
 }
//*********************************************************************************************************
// Trama DHT11 - Segun Datasheet
// ____             ____      ____                                       ___
//     |___________|    |____|    |.....................................|
//     |   18ms    |    |80us|80us|               5x8 bit               |
//     |    PIC    |    |                  DHT11 respuesta              | Fin de
//     |  request  |    |  2x80us, intRH, decRH, intT, decT, checksum   | Trama
// ____          ________
//     |________|        |...                        0 bit
//      <-50us-> <-27us->
// ____          _________________________
//     |________|                         |...       1 bit
//      <-50us-> <---------70us---------->
//*********************************************************************************************************
unsigned int trama[5];                                       //Vector donde se alojan los datos
//*********************************************************************************************************
// Funcion de recepcio de Byte
// Lee el valor leido en la trama y lo separa realizando shift
// Retorna el valor en forma de byte, es utilizado en la funcion recibeDato()
//*********************************************************************************************************
unsigned int recibeByte(){                                   //Funcion que recibe un Byte
   unsigned int valorLeido = 0;                              //Valor de retorno de la funcion
   int i=0;                                                  //Inicializacion del indice
   for(i=0; i<8; i++){                                       //Iteracion para recepcion de bits
      valorLeido <<= 1;                                      //Registro de desplazamiento de bits
      while(DATA==0);                                        //Espera a DATA = 0
      delay_us(30);                                          //Demora de 30us (Del Datasheet)
      if(DATA==1){                                           //Pregunta si DATA = 1
          valorLeido |= 1;                                   //Realiza toggle del valor leido
      }
      while(DATA==1);                                        //Espera a DATA = 1
   }
   return valorLeido;                                        //Retorna el valor leido
}
//*********************************************************************************************************
// Funcion de recepcion de dato para el DHT11
// Recive los valores de temperatura y humedad (parte entera y decimales por separado)
// Recive el checksum enviado por el DHT11 y lo compara con el leido en el programa
//*********************************************************************************************************
unsigned int recibeDato(){                                   //Funcion que recibe el Dato
   int validacion = 0;                                       //Variable de Validacion
   int checksum = 0;                                         //Variable de deteccion de cambios de secuencia
   int j=0;                                                  //Variable para el lazo for
   DATA = 1;                                                 //Set DATA = 1  
   DATA = 0;                                                 //Set DATA = 0
   delay_ms(18);                                             //Demora de 18ms (Del Datasheet)
   DATA = 1;                                                 //Set DATA = 1
   delay_us(25);                                             //Demora de 25ms (Del Datasheet)
   validacion = DATA;                                        //Mueve valor de DATA a Validacion
   delay_us(80);                                             //Espera 80us (Del Datasheet)
   validacion = DATA;                                        //Mueve valor de DATA a Validacion
   if(!validacion){                                          //Si Validacion = 0, Error de secuencia
      printf( "Error en Checksum \r");                       //Muestra leyenda de error
   }
   delay_us(80);                                             //Espera 80us (Del Datasheet)
   for(j=0; j<5; j++){                                       //Lazo de carga de bytes de datos
       trama[j] = recibeByte();                              //Carga del vector de datos
   }
   DATA = 1;                                                 //Set DATA = 1
   for(j=0; j<4; j++){                                       //Lazo de carga de bytes de verificacion
       checksum += trama[j];                                 //Carga de bytes de verificacion
   }
   if(checksum == trama[4]){                                 //Si la secuencia de verificacion es correcta
      return 0;                                              //Se retorna 0 y se realiza la lectura
   }
}
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
void main(){                                                 //Funcion principal
   saludoPantalla();                                         //Función de saludo de pantalla
   P1=0x00;                                                  //Usado para aplicacion
   P3=0x03;                                                  //Usado para el serie
   serialInit();                                             //Inicializa puerto serie
   EA=1;                                                     //Habilitacion de interrupcion Global
   ES=1;                                                     //Habilitacion de interrupcion Serie
   while(1){                                                 //Loop principal infinito
      leeDHT11();                                            //Funcion que lee DHT11
      delay_ms(2000);                                        //delay_ms de Actualizacion
      impPantalla();                                         //Imprime pantalla LCD
      delay_ms(2000);                                        //delay_ms de Actualizacion
   }
}

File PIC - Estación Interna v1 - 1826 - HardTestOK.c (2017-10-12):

//*********************************************************************************************************
// Programa para la estación meteorológica Interna inalámbrica
// El programa recibe Temperatura, Humedad y Luminosidad por interrupción
// El sistema mide Temperatura y Humedad interior
// El enlace se realiza mediante una comunicación ASK OOK UHF sobre UART Invertido a 600bps
// Se muestra medición interna y externa en un LCD de 2x16
//*********************************************************************************************************
#include <16F1826.h>                                           //Biblioteca del microcontrolador
#fuses NOMCLR, NOWDT, INTRC_IO                                 //Configuración de fuses
#use delay(int=4000000)                                        //Configuración del clock interno a 4MHz
#use rs232(baud=600,parity=N,xmit=PIN_B2,rcv=PIN_B1,bits=8)    //Configuración de UART 600bps 8 N 1
#define LCD_ENABLE_PIN  PIN_A7                                 //Redefine pin de LCD
#define LCD_RS_PIN      PIN_A4                                 //Redefine pin de LCD
#define LCD_RW_PIN      PIN_A6                                 //Redefine pin de LCD
#define LCD_DATA4       PIN_B4                                 //Redefine pin de LCD
#define LCD_DATA5       PIN_B5                                 //Redefine pin de LCD
#define LCD_DATA6       PIN_B6                                 //Redefine pin de LCD
#define LCD_DATA7       PIN_B7                                 //Redefine pin de LCD
#include <LCD.c>                                               //biblioteca del LCD 2x16
//*********************************************************************************************************
// Variables
//*********************************************************************************************************
#define HEADER 200                                             //Definición de valor Header para el payload
#define DATA PIN_A3                                            //Pin del bus de un hilo para el DHT11
#define STATUS PIN_A1                                          //Pin para analizar el status de la interrupt
static int8 datoInt[2];                                        //Variable donde se alojan los datos internos
static int8 payload[5];                                        //Variable donde se aloja el payload
static int8 datoExt[3];                                        //Variable donde se alojan los datos externos
//*********************************************************************************************************
// Función Interrupción UART que realiza el parse de datos, validación de Header y Checksum
// Si validación y Checksum son validos, carga el vector DATO para ser utilizado
//*********************************************************************************************************
int8 i=0;                                                      //Variable para el contador de bytes de entrada
#int_RDA                                                       //Interrupción por dato en UART
void intser(){                                                 //Función de servicio de interrupción
   payload[i++]=getc();                                        //Guarda byte de entrada en payload. incrementa indice
   if(i>5){                                                    //Si el indice es mayor que 5 se asume que se completa el payload
      if(payload[0]==HEADER){                                  //Validación que el Header sea 200 (seteado en el transmisor)
         if(payload[1]+payload[2]+payload[3]-payload[4]==0){   //Validación de checksum, si datos leídos son igual a checksum
            datoExt[0]=payload[1];                             //Cargamos los datos en el vector
            datoExt[1]=payload[2];                             //Cargamos los datos en el vector
            datoExt[2]=payload[3];                             //Cargamos los datos en el vector
            output_toggle(STATUS);                             //Status de dato recibido OK
         }
      }
      i=0;                                                     //Una vez que se completan los 5 bytes, se reinicia el contador
   }
}
//*********************************************************************************************************
// Trama DHT11 - Segun Datasheet
// ____             ____      ____                                       ___
//     |___________|    |____|    |.....................................|
//     |   18ms    |    |80us|80us|               5x8 bit               |
//     |    PIC    |    |                  DHT11 respuesta              | Fin de
//     |  request  |    |  2x80us, intRH, decRH, intT, decT, checksum   | Trama
// ____          ________
//     |________|        |...                        0 bit
//      <-50us-> <-27us->
// ____          _________________________
//     |________|                         |...       1 bit
//      <-50us-> <---------70us---------->
//*********************************************************************************************************
unsigned int trama[5];                                         //Vector donde se alojan los datos
//*********************************************************************************************************
// Función de recepción de Byte
// Lee el valor leído en la trama y lo separa realizando shift
// Retorna el valor en forma de byte, es utilizado en la función recibeDato()
//*********************************************************************************************************
unsigned int recibeByte(){                                     //Función que recibe un Byte
   unsigned int8 valorLeido = 0;                               //Valor de retorno de la función
   int8 i=0;                                                   //Inicialización del indice
   for(i=0; i<8; i++){                                         //Iteración para recepción de bits
      valorLeido <<= 1;                                        //Registro de desplazamiento de bits
      while(!input(DATA));                                     //Espera a DATA = 0
      delay_us(30);                                            //Demora de 30us (Del Datasheet)
      if(input(DATA)){                                         //Pregunta si DATA = 1
          valorLeido |= 1;                                     //Realiza toggle del valor leido
      }
      while(input(DATA));                                      //Espera a DATA = 1
   }
   return valorLeido;                                          //Retorna el valor leido
}
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

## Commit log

2017-10-12 Rename Manual de Usuario.gdoc to documentos/Manual de Usuario.gdoc
2017-11-08 modificaciones finales
    [Estación Meteorológica.stl, UTN-ESEXT01.brd, UTN-ESEXT01.csv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]

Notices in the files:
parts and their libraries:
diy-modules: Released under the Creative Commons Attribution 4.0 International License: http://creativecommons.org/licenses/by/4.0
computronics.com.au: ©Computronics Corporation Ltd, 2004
